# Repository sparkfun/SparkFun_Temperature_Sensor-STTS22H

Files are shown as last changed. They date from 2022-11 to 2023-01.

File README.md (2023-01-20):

SparkFun Temperature Sensor STTS22H
========================================

<table class="table table-hover table-striped table-bordered">
    <tr>
        <th class="text-center"> 
        </th>
        <th class="text-center">
        </th>
    </tr>
    <tr align="center">
        <td></td>
        <td></td>
    </tr>
    <tr align="center">
        <td><a href="https://www.sparkfun.com/products/21262">SparkFun Temperature Sensor - STTS22H (Qwiic)</a></td>
        <td><a href="https://www.sparkfun.com/products/21273">SparkFun Micro Temperature Sensor - STTS22H (Qwiic)</a></td>
    </tr>
</table>

The [SparkFun Temperature Sensor - STTS22H (Qwiic)](https://www.sparkfun.com/products/21262) and the [SparkFun Micro Temperature Sensor - STTS22H (Qwiic)](https://www.sparkfun.com/products/21273) are Qwiic enabled breakout boards based on the ultralow-power, high-accuracy, digital temperature sensor STTS22H from ST Microelectronics. Thanks to its factory calibration the STTS22H offers high-end accuracy performance over the entire operating temperature range, reaching as low as ±0.5 °C without requiring any further calibration at the application level. 

Repository Contents
-------------------

* **/Documentation** - Data sheets, additional product information
* **/Hardware** - Eagle design files (.brd, .sch)
* **/Production** - Production panel files (.brd)

Documentation
--------------
* **[Library](https://github.com/sparkfun/SparkFun_STTS22H_Arduino_Library)** - Arduino library for the SparkFun Temperature Sensor STTS22H.
* **[Hookup Guide](https://learn.sparkfun.com/tutorials/sparkfun-temperature-sensor---stts22h-qwiic-hookup-guide)** - Basic hookup guide for the SparkFun Temperature Sensor STTS22H.

License Information
-------------------

This product is _**open source**_! 

Please review the LICENSE.md file for license information. 

If you have any questions or concerns on licensing, please contact technical support on our [SparkFun forums](https://forum.sparkfun.com/viewforum.php?f=152).

Distributed as-is; no warranty is given.

- Your friends at SparkFun.

_<COLLABORATION CREDIT>_

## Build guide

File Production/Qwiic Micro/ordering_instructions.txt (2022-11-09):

panel size, 170x79mm
PCB thickness, 1.6mm
number of layers, 2
soldermask color, Red
silkscreen color, White
oz copper, 1oz
finish, HASL lead free
stencils, top
pcs per panel, 64
min trace width, 0.1524mm / 0.0060in
min drill size, 0.2032mm / 0.0080in

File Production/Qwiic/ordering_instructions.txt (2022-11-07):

panel size, 169x117mm
PCB thickness, 1.6mm
number of layers, 2
soldermask color, Red
silkscreen color, White
oz copper, 1oz
finish, HASL lead free
stencils, top
pcs per panel, 24
min trace width, 0.2032mm / 0.0080in
min drill size, 0.2032mm / 0.0080in

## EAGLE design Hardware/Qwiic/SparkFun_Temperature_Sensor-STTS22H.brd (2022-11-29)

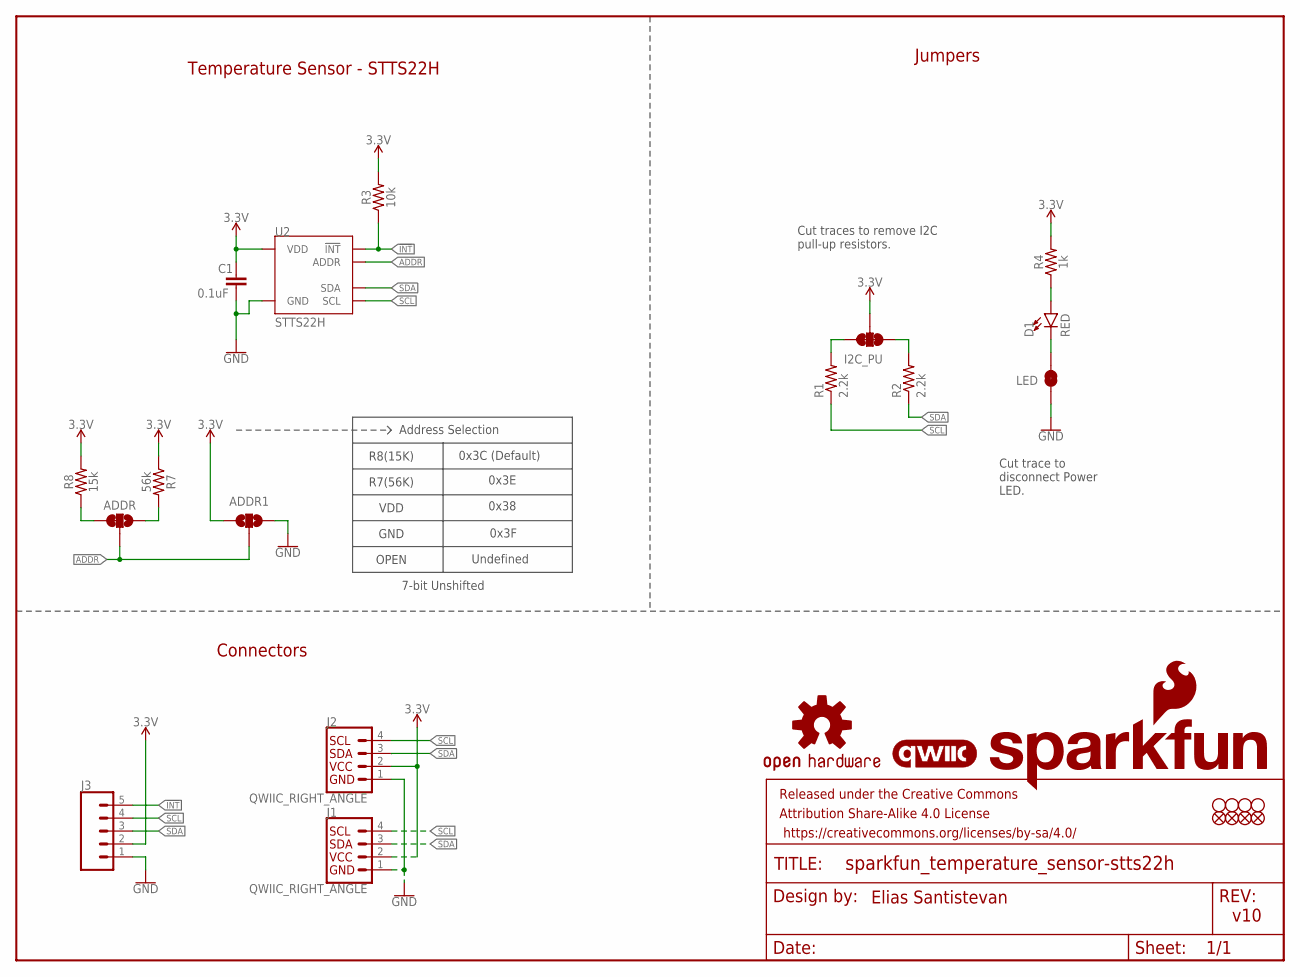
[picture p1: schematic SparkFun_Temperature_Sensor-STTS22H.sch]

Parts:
ADDR: JUMPER-SMT_3_1-NC_TRACE_SILK; SMT-JUMPER_3_1-NC_TRACE_SILK
ADDR1: JUMPER-SMT_3_NO_SILK; SMT-JUMPER_3_NO_SILK
C1: 0.1uF; 0603
D1: RED; LED-0603
FD1, FD2, FD3, FD4: FIDUCIAL1X2; FIDUCIAL-1X2
FRAME1: FRAME-LETTER; CREATIVE_COMMONS
I2C_PU: S_MODE; SMT-JUMPER_3_2-NC_TRACE_SILK
J1, J2: QWIIC_RIGHT_ANGLE; JST04_1MM_RA
J3: CONN_05NO_SILK; 1X05_NO_SILK
LED: JUMPER-SMT_2_NC_TRACE_SILK; SMT-JUMPER_2_NC_TRACE_SILK
LOGO2: OSHW-LOGOMINI; OSHW-LOGO-MINI
LOGO3: SFE_LOGO_NAME_FLAME.1_INCH; SFE_LOGO_NAME_FLAME_.1
LOGO4: QWIIC_LOGO_4MM; QWIIC_4MM
R1, R2: 2.2k; 0603
R3: 10k; 0603
R4: 1k; 0603
R7: 56k; 0603
R8: 15k; 0603
STANDOFF1, STANDOFF2, STANDOFF3, STANDOFF5: STAND-OFFTIGHT; STAND-OFF-TIGHT
U2: STTS22H; UDFN-6L

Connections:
3.3V: ADDR1.3, C1.1, I2C_PU.2, J1.2, J2.2, J3.2, R3.2, R4.2, R7.1, R8.2, U2.P3 (VDD)
!INT!: J3.5, R3.1, U2.P2 (!INT!)
ADDR: ADDR.2, ADDR1.2, U2.P4 (ADDR)
GND: ADDR1.1, C1.2, J1.1, J2.1, J3.1, LED.1, U2.P5 (GND), U2.P7 (GND)
unnamed: D1.A, R4.1
unnamed: D1.C, LED.2
unnamed: ADDR.3, R8.1
unnamed: I2C_PU.1, R1.2
unnamed: I2C_PU.3, R2.2
unnamed: ADDR.1, R7.2
SCL: J1.4, J2.4, J3.4, R1.1, U2.P1 (SCL)
SDA: J1.3, J2.3, J3.3, R2.1, U2.P6 (SDA)

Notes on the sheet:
Cut traces to remove I2C pull-up resistors.
v10
Jumpers
Cut trace to disconnect Power LED.
Connectors
Elias Santistevan
VDD
GND
OPEN
Undefined
7-bit Unshifted
R7(56K)
R8(15K)
0x38
0x3C (Default)
0x3E
0x3F
Temperature Sensor - STTS22H
Address Selection

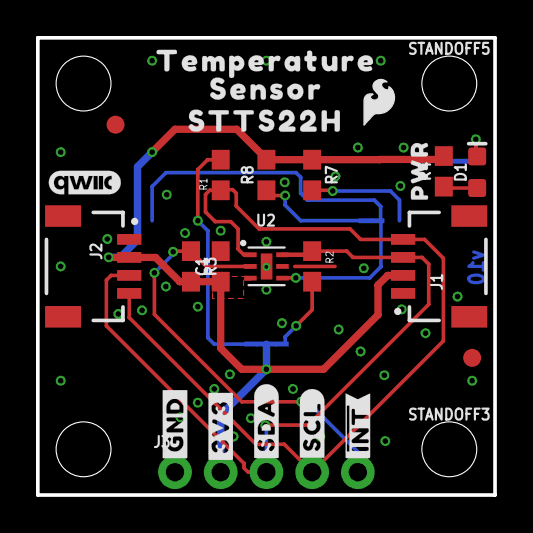
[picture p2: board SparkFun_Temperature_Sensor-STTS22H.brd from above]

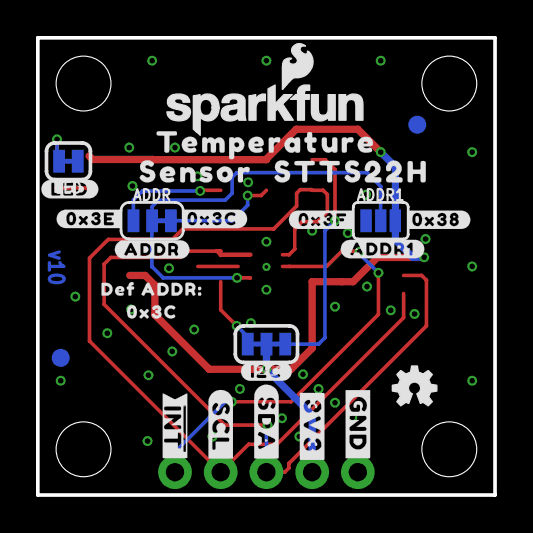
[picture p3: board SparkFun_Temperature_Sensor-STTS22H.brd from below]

Board: 2 copper layers, 25.4 x 25.4 mm, 56 parts (26 on the bottom side), 12 nets.

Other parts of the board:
U$1, U$9: #GND#3
U$2, U$10: #3V3#4
U$3: #SDA#5
U$4: #SCL#4
U$5: #SDA#7
U$6: #ADDR#6
U$7: #SCL#6
U$8: #ADDR1#9
U$11: ##INT##9
U$12: #0X3C#25
U$13: #0X3E#25
U$14: #0X3F#25
U$15: #0X38#25
U$16: #LED#11
U$17, U$23: TEMPERATURE23
U$18: ##INT##6
U$19, U$24: SENSOR24
U$20: SFE_LOGO_FLAME_.1
U$21: PWR9
U$22, U$26: STTS22H21
U$25: #I2C#11
U$27: DEF_ADDR#29
U$28: 0X3C30

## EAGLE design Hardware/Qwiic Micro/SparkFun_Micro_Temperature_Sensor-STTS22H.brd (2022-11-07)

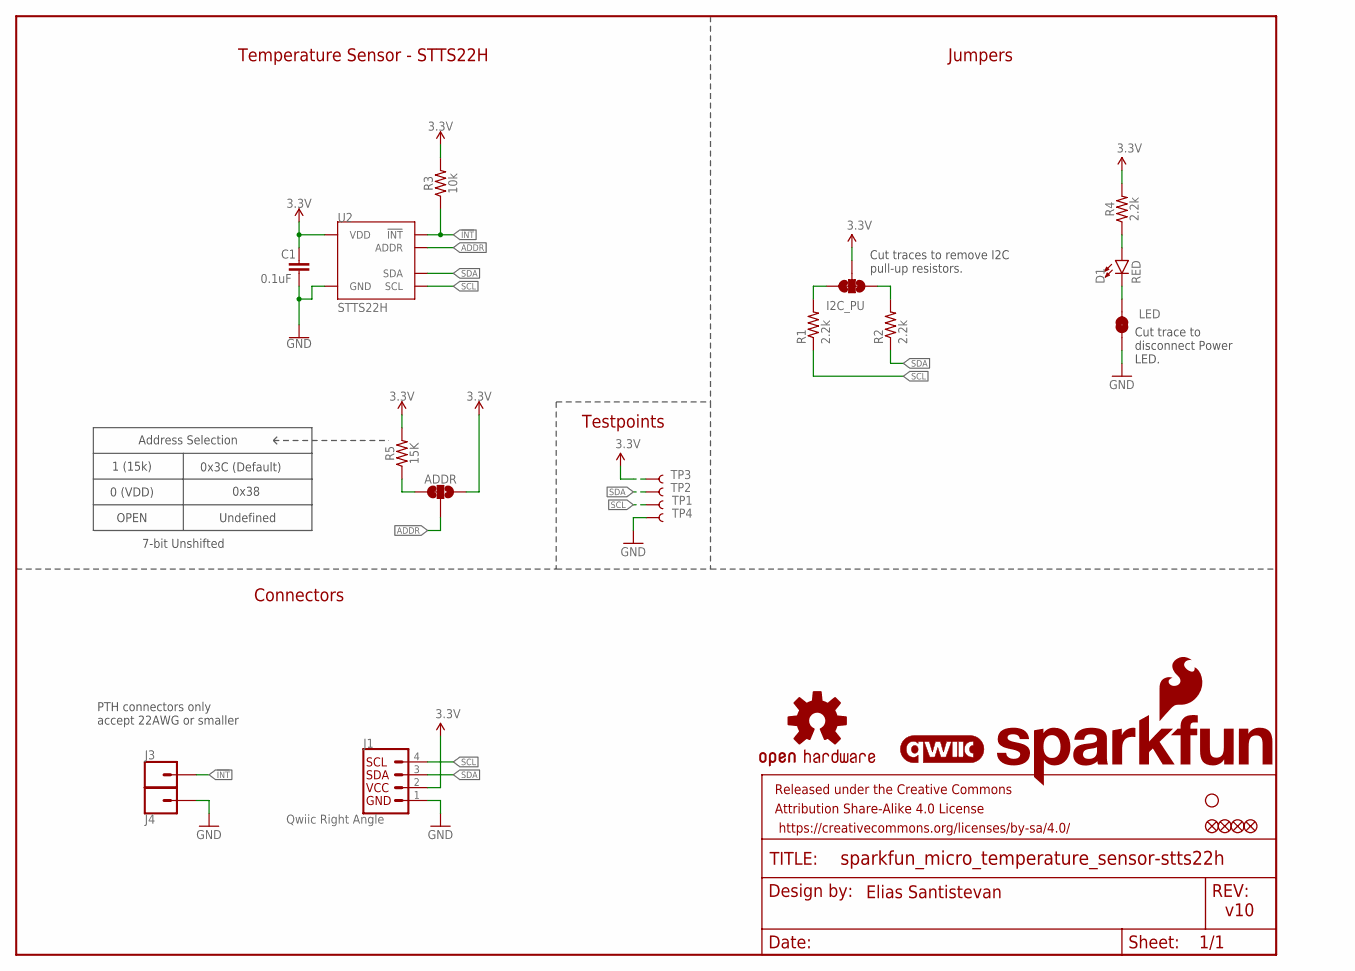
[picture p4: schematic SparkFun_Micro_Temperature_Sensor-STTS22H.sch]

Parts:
ADDR: JUMPER-SMT_3_1-NC_TRACE_SILK; SMT-JUMPER_3_1-NC_TRACE_SILK
C1: 0.1uF; 0402-TIGHT
D1: RED; LED-0402
FD1, FD2: FIDUCIALUFIDUCIAL; FIDUCIAL-MICRO
FID1, FID2: FIDUCIALUFIDUCIAL; FIDUCIAL-MICRO
FRAME1: FRAME-LETTER; CREATIVE_COMMONS
I2C_PU: S_MODE; SMT-JUMPER_3_2-NC_TRACE_SILK
J1: Qwiic Right Angle; JST04_1MM_RA
J3, J4: CONN_01_1MM; 1X01_1MM_NO_SILK
LED: JUMPER-SMT_2_NC_TRACE_SILK; SMT-JUMPER_2_NC_TRACE_SILK
LOGO1: QWIIC_LOGO_3MM; QWIIC_3MM
LOGO2: OSHW-LOGOMINI; OSHW-LOGO-MINI
LOGO3: SFE_LOGO_NAME_FLAMEBLANK; BLANK
R1, R2, R4: 2.2k; 0402-TIGHT
R3: 10k; 0402-TIGHT
R5: 15K; 0402-TIGHT
STANDOFF1: STAND-OFFTIGHT; STAND-OFF-TIGHT
TP1, TP2, TP3, TP4: TEST-POINT3; PAD.03X.03
U2: STTS22H; UDFN-6L

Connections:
3.3V: ADDR.1, C1.1, I2C_PU.2, J1.2, R3.2, R4.2, R5.2, TP3.1, U2.P3 (VDD)
!INT!: J3.1, R3.1, U2.P2 (!INT!)
ADDR: ADDR.2, U2.P4 (ADDR)
GND: C1.2, J1.1, J4.1, LED.1, TP4.1, U2.P5 (GND), U2.P7 (GND)
unnamed: ADDR.3, R5.1
unnamed: D1.A, R4.1
unnamed: D1.C, LED.2
unnamed: I2C_PU.1, R1.2
unnamed: I2C_PU.3, R2.2
SCL: J1.4, R1.1, TP1.1, U2.P1 (SCL)
SDA: J1.3, R2.1, TP2.1, U2.P6 (SDA)

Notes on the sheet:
Cut traces to remove I2C pull-up resistors.
v10
Jumpers
Cut trace to disconnect Power LED.
Connectors
Elias Santistevan
Testpoints
PTH connectors only accept 22AWG or smaller
1 (15k)
0 (VDD)
OPEN
Undefined
7-bit Unshifted
0x3C (Default)
0x38
Temperature Sensor - STTS22H
Address Selection

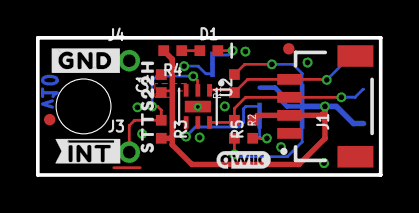
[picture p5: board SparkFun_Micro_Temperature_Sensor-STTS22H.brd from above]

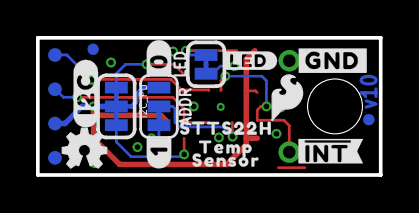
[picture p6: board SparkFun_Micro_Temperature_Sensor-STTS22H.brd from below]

Board: 2 copper layers, 19.1 x 7.6 mm, 40 parts (20 on the bottom side), 11 nets.

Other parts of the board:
U$1: #0#4
U$2: #1#4
U$3: #LED#2121
U$4, U$10: #GND#4
U$5, U$6: ##INT##9
U$7, U$8: STTS22H11
U$9: TEMP24
U$11: SENSOR25
U$12: #I2C#4
U$29: SFE_LOGO_FLAME_.1

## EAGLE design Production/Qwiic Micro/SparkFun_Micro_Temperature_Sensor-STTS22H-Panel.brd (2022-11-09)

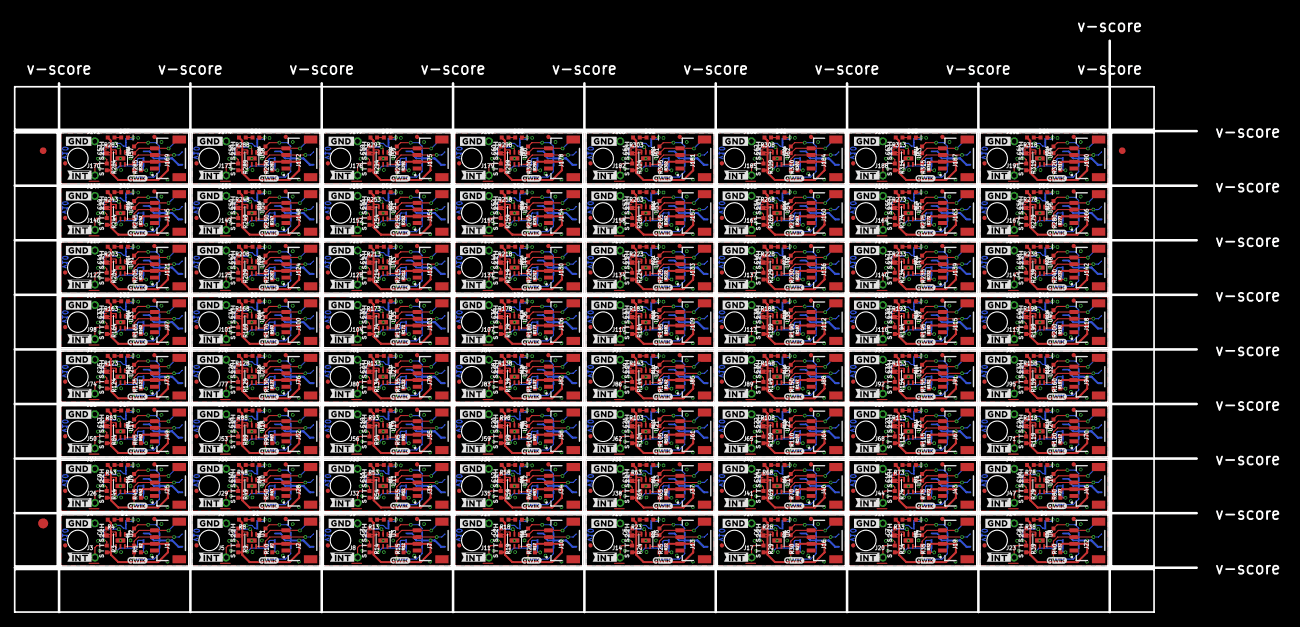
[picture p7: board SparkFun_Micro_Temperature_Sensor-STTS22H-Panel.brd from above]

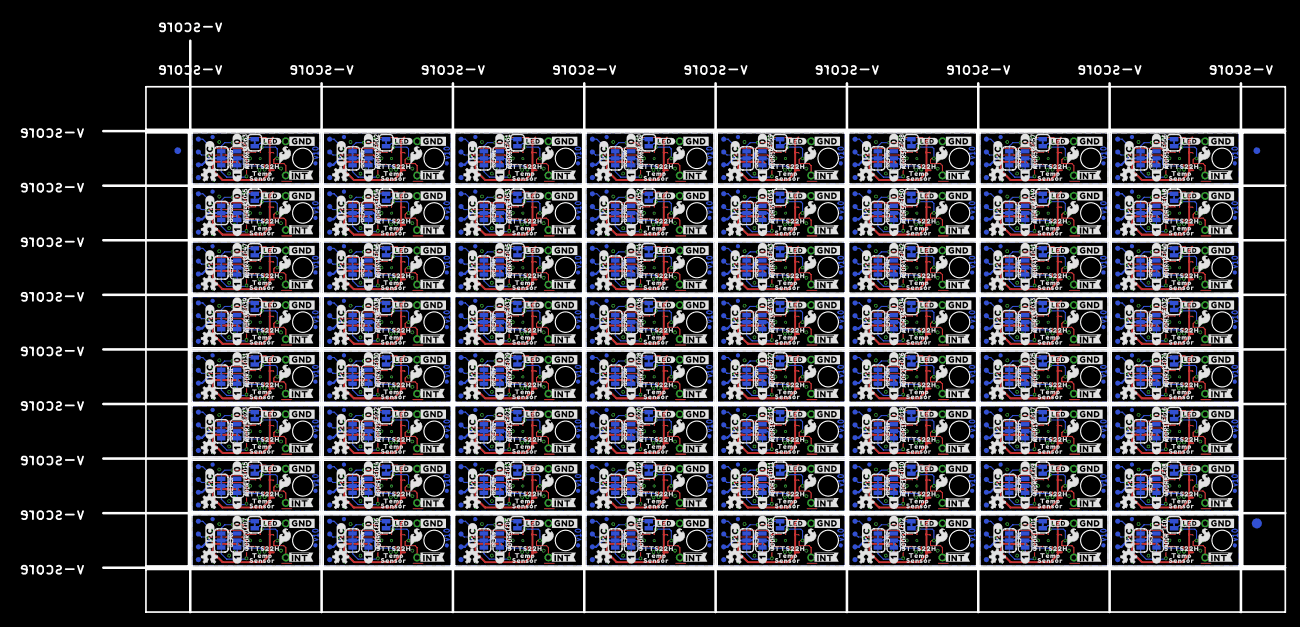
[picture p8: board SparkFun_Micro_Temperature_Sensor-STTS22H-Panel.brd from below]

Board: 2 copper layers, 176.0 x 85.1 mm, 2502 parts (1283 on the bottom side), 704 nets.

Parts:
ADDR, ADDR1, ADDR2, ADDR3, ADDR4, ADDR5, ADDR6, ADDR7, ADDR8, ADDR9, ADDR10, ADDR11, ADDR12, ADDR13, ADDR14, ADDR15, ADDR16, ADDR17, ADDR18, ADDR19, ADDR20, ADDR21, ADDR22, ADDR23, ADDR24, ADDR25, ADDR26, ADDR27, ADDR28, ADDR29, ADDR30, ADDR31, ADDR32, ADDR33, ADDR34, ADDR35, ADDR36, ADDR37, ADDR38, ADDR39, ADDR40, ADDR41, ADDR42, ADDR43, ADDR44, ADDR45, ADDR46, ADDR47, ADDR48, ADDR49, ADDR50, ADDR51, ADDR52, ADDR53, ADDR54, ADDR55, ADDR56, ADDR57, ADDR58, ADDR59, ADDR60, ADDR61, ADDR62, ADDR63: JUMPER-SMT_3_1-NC_TRACE_SILK; SMT-JUMPER_3_1-NC_TRACE_SILK
C1, C2, C3, C4, C5, C6, C7, C8, C9, C10, C11, C12, C13, C14, C15, C16, C17, C18, C19, C20, C21, C22, C23, C24, C25, C26, C27, C28, C29, C30, C31, C32, C33, C34, C35, C36, C37, C38, C39, C40, C41, C42, C43, C44, C45, C46, C47, C48, C49, C50, C51, C52, C53, C54, C55, C56, C57, C58, C59, C60, C61, C62, C63, C64: 0.1uF; 0402-TIGHT
D1, D2, D3, D4, D5, D6, D7, D8, D9, D10, D11, D12, D13, D14, D15, D16, D17, D18, D19, D20, D21, D22, D23, D24, D25, D26, D27, D28, D29, D30, D31, D32, D33, D34, D35, D36, D37, D38, D39, D40, D41, D42, D43, D44, D45, D46, D47, D48, D49, D50, D51, D52, D53, D54, D55, D56, D57, D58, D59, D60, D61, D62, D63, D64: RED; LED-0402
E$1, E$2, E$3, E$4: FIDUCIAL-1X2
E$5, E$6: FIDUCIAL-1.5X3
FD1, FD2, FD3, FD4, FD5, FD6, FD7, FD8, FD9, FD10, FD11, FD12, FD13, FD14, FD15, FD16, FD17, FD18, FD19, FD20, FD21, FD22, FD23, FD24, FD25, FD26, FD27, FD28, FD29, FD30, FD31, FD32, FD33, FD34, FD35, FD36, FD37, FD38, FD39, FD40, FD41, FD42, FD43, FD44, FD45, FD46, FD47, FD48, FD49, FD50, FD51, FD52, FD53, FD54, FD55, FD56, FD57, FD58, FD59, FD60, FD61, FD62, FD63, FD64, FD65, FD66, FD67, FD68, FD69, FD70, FD71, FD72, FD73, FD74, FD75, FD76, FD77, FD78, FD79, FD80, FD81, FD82, FD83, FD84, FD85, FD86, FD87, FD88, FD89, FD90, FD91, FD92, FD93, FD94, FD95, FD96, FD97, FD98, FD99, FD100, FD101, FD102, FD103, FD104, FD105, FD106, FD107, FD108, FD109, FD110, FD111, FD112, FD113, FD114, FD115, FD116, FD117, FD118, FD119, FD120, FD121, FD122, FD123, FD124, FD125, FD126, FD127, FD128: FIDUCIALUFIDUCIAL; FIDUCIAL-MICRO
FID1, FID2, FID3, FID4, FID5, FID6, FID7, FID8, FID9, FID10, FID11, FID12, FID13, FID14, FID15, FID16, FID17, FID18, FID19, FID20, FID21, FID22, FID23, FID24, FID25, FID26, FID27, FID28, FID29, FID30, FID31, FID32, FID33, FID34, FID35, FID36, FID37, FID38, FID39, FID40, FID41, FID42, FID43, FID44, FID45, FID46, FID47, FID48, FID49, FID50, FID51, FID52, FID53, FID54, FID55, FID56, FID57, FID58, FID59, FID60, FID61, FID62, FID63, FID64, FID65, FID66, FID67, FID68, FID69, FID70, FID71, FID72, FID73, FID74, FID75, FID76, FID77, FID78, FID79, FID80, FID81, FID82, FID83, FID84, FID85, FID86, FID87, FID88, FID89, FID90, FID91, FID92, FID93, FID94, FID95, FID96, FID97, FID98, FID99, FID100, FID101, FID102, FID103, FID104, FID105, FID106, FID107, FID108, FID109, FID110, FID111, FID112, FID113, FID114, FID115, FID116, FID117, FID118, FID119, FID120, FID121, FID122, FID123, FID124, FID125, FID126, FID127, FID128: FIDUCIALUFIDUCIAL; FIDUCIAL-MICRO
I2C_PU, I2C_PU1, I2C_PU2, I2C_PU3, I2C_PU4, I2C_PU5, I2C_PU6, I2C_PU7, I2C_PU8, I2C_PU9, I2C_PU10, I2C_PU11, I2C_PU12, I2C_PU13, I2C_PU14, I2C_PU15, I2C_PU16, I2C_PU17, I2C_PU18, I2C_PU19, I2C_PU20, I2C_PU21, I2C_PU22, I2C_PU23, I2C_PU24, I2C_PU25, I2C_PU26, I2C_PU27, I2C_PU28, I2C_PU29, I2C_PU30, I2C_PU31, I2C_PU32, I2C_PU33, I2C_PU34, I2C_PU35, I2C_PU36, I2C_PU37, I2C_PU38, I2C_PU39, I2C_PU40, I2C_PU41, I2C_PU42, I2C_PU43, I2C_PU44, I2C_PU45, I2C_PU46, I2C_PU47, I2C_PU48, I2C_PU49, I2C_PU50, I2C_PU51, I2C_PU52, I2C_PU53, I2C_PU54, I2C_PU55, I2C_PU56, I2C_PU57, I2C_PU58, I2C_PU59, I2C_PU60, I2C_PU61, I2C_PU62, I2C_PU63: S_MODE; SMT-JUMPER_3_2-NC_TRACE_SILK
J1, J2, J7, J10, J13, J16, J19, J22, J25, J28, J31, J34, J37, J40, J43, J46, J49, J52, J55, J58, J61, J64, J67, J70, J73, J76, J79, J82, J85, J88, J91, J94, J97, J100, J103, J106, J109, J112, J115, J118, J121, J124, J127, J130, J133, J136, J139, J142, J145, J148, J151, J154, J157, J160, J163, J166, J169, J172, J175, J178, J181, J184, J187, J190: Qwiic Right Angle; JST04_1MM_RA
J3, J4, J5, J6, J8, J9, J11, J12, J14, J15, J17, J18, J20, J21, J23, J24, J26, J27, J29, J30, J32, J33, J35, J36, J38, J39, J41, J42, J44, J45, J47, J48, J50, J51, J53, J54, J56, J57, J59, J60, J62, J63, J65, J66, J68, J69, J71, J72, J74, J75, J77, J78, J80, J81, J83, J84, J86, J87, J89, J90, J92, J93, J95, J96, J98, J99, J101, J102, J104, J105, J107, J108, J110, J111, J113, J114, J116, J117, J119, J120, J122, J123, J125, J126, J128, J129, J131, J132, J134, J135, J137, J138, J140, J141, J143, J144, J146, J147, J149, J150, J152, J153, J155, J156, J158, J159, J161, J162, J164, J165, J167, J168, J170, J171, J173, J174, J176, J177, J179, J180, J182, J183, J185, J186, J188, J189, J191, J192: 1X01_1MM_NO_SILK
LED, LED1, LED2, LED3, LED4, LED5, LED6, LED7, LED8, LED9, LED10, LED11, LED12, LED13, LED14, LED15, LED16, LED17, LED18, LED19, LED20, LED21, LED22, LED23, LED24, LED25, LED26, LED27, LED28, LED29, LED30, LED31, LED32, LED33, LED34, LED35, LED36, LED37, LED38, LED39, LED40, LED41, LED42, LED43, LED44, LED45, LED46, LED47, LED48, LED49, LED50, LED51, LED52, LED53, LED54, LED55, LED56, LED57, LED58, LED59, LED60, LED61, LED62, LED63: JUMPER-SMT_2_NC_TRACE_SILK; SMT-JUMPER_2_NC_TRACE_SILK
LOGO1, LOGO5, LOGO8, LOGO11, LOGO14, LOGO17, LOGO20, LOGO23, LOGO26, LOGO29, LOGO32, LOGO35, LOGO38, LOGO41, LOGO44, LOGO47, LOGO50, LOGO53, LOGO56, LOGO59, LOGO62, LOGO65, LOGO68, LOGO71, LOGO74, LOGO77, LOGO80, LOGO83, LOGO86, LOGO89, LOGO92, LOGO95, LOGO98, LOGO101, LOGO104, LOGO107, LOGO110, LOGO113, LOGO116, LOGO119, LOGO122, LOGO125, LOGO128, LOGO131, LOGO134, LOGO137, LOGO140, LOGO143, LOGO146, LOGO149, LOGO152, LOGO155, LOGO158, LOGO161, LOGO164, LOGO167, LOGO170, LOGO173, LOGO176, LOGO179, LOGO182, LOGO185, LOGO188, LOGO191: QWIIC_LOGO_3MM; QWIIC_3MM
LOGO2, LOGO4, LOGO7, LOGO10, LOGO13, LOGO16, LOGO19, LOGO22, LOGO25, LOGO28, LOGO31, LOGO34, LOGO37, LOGO40, LOGO43, LOGO46, LOGO49, LOGO52, LOGO55, LOGO58, LOGO61, LOGO64, LOGO67, LOGO70, LOGO73, LOGO76, LOGO79, LOGO82, LOGO85, LOGO88, LOGO91, LOGO94, LOGO97, LOGO100, LOGO103, LOGO106, LOGO109, LOGO112, LOGO115, LOGO118, LOGO121, LOGO124, LOGO127, LOGO130, LOGO133, LOGO136, LOGO139, LOGO142, LOGO145, LOGO148, LOGO151, LOGO154, LOGO157, LOGO160, LOGO163, LOGO166, LOGO169, LOGO172, LOGO175, LOGO178, LOGO181, LOGO184, LOGO187, LOGO190: OSHW-LOGOMINI; OSHW-LOGO-MINI
LOGO3, LOGO6, LOGO9, LOGO12, LOGO15, LOGO18, LOGO21, LOGO24, LOGO27, LOGO30, LOGO33, LOGO36, LOGO39, LOGO42, LOGO45, LOGO48, LOGO51, LOGO54, LOGO57, LOGO60, LOGO63, LOGO66, LOGO69, LOGO72, LOGO75, LOGO78, LOGO81, LOGO84, LOGO87, LOGO90, LOGO93, LOGO96, LOGO99, LOGO102, LOGO105, LOGO108, LOGO111, LOGO114, LOGO117, LOGO120, LOGO123, LOGO126, LOGO129, LOGO132, LOGO135, LOGO138, LOGO141, LOGO144, LOGO147, LOGO150, LOGO153, LOGO156, LOGO159, LOGO162, LOGO165, LOGO168, LOGO171, LOGO174, LOGO177, LOGO180, LOGO183, LOGO186, LOGO189, LOGO192: SFE_LOGO_NAME_FLAMEBLANK; BLANK
R1, R2, R4, R6, R7, R8, R11, R12, R13, R16, R17, R18, R21, R22, R23, R26, R27, R28, R31, R32, R33, R36, R37, R38, R41, R42, R43, R46, R47, R48, R51, R52, R53, R56, R57, R58, R61, R62, R63, R66, R67, R68, R71, R72, R73, R76, R77, R78, R81, R82, R83, R86, R87, R88, R91, R92, R93, R96, R97, R98, R101, R102, R103, R106, R107, R108, R111, R112, R113, R116, R117, R118, R121, R122, R123, R126, R127, R128, R131, R132, R133, R136, R137, R138, R141, R142, R143, R146, R147, R148, R151, R152, R153, R156, R157, R158, R161, R162, R163, R166, R167, R168, R171, R172, R173, R176, R177, R178, R181, R182, R183, R186, R187, R188, R191, R192, R193, R196, R197, R198, R201, R202, R203, R206, R207, R208, R211, R212, R213, R216, R217, R218, R221, R222, R223, R226, R227, R228, R231, R232, R233, R236, R237, R238, R241, R242, R243, R246, R247, R248, R251, R252, R253, R256, R257, R258, R261, R262, R263, R266, R267, R268, R271, R272, R273, R276, R277, R278, R281, R282, R283, R286, R287, R288, R291, R292, R293, R296, R297, R298, R301, R302, R303, R306, R307, R308, R311, R312, R313, R316, R317, R318: 2.2k; 0402-TIGHT
R3, R9, R14, R19, R24, R29, R34, R39, R44, R49, R54, R59, R64, R69, R74, R79, R84, R89, R94, R99, R104, R109, R114, R119, R124, R129, R134, R139, R144, R149, R154, R159, R164, R169, R174, R179, R184, R189, R194, R199, R204, R209, R214, R219, R224, R229, R234, R239, R244, R249, R254, R259, R264, R269, R274, R279, R284, R289, R294, R299, R304, R309, R314, R319: 10k; 0402-TIGHT
R5, R10, R15, R20, R25, R30, R35, R40, R45, R50, R55, R60, R65, R70, R75, R80, R85, R90, R95, R100, R105, R110, R115, R120, R125, R130, R135, R140, R145, R150, R155, R160, R165, R170, R175, R180, R185, R190, R195, R200, R205, R210, R215, R220, R225, R230, R235, R240, R245, R250, R255, R260, R265, R270, R275, R280, R285, R290, R295, R300, R305, R310, R315, R320: 15K; 0402-TIGHT
STANDOFF1, STANDOFF2, STANDOFF3, STANDOFF4, STANDOFF5, STANDOFF6, STANDOFF7, STANDOFF8, STANDOFF9, STANDOFF10, STANDOFF11, STANDOFF12, STANDOFF13, STANDOFF14, STANDOFF15, STANDOFF16, STANDOFF17, STANDOFF18, STANDOFF19, STANDOFF20, STANDOFF21, STANDOFF22, STANDOFF23, STANDOFF24, STANDOFF25, STANDOFF26, STANDOFF27, STANDOFF28, STANDOFF29, STANDOFF30, STANDOFF31, STANDOFF32, STANDOFF33, STANDOFF34, STANDOFF35, STANDOFF36, STANDOFF37, STANDOFF38, STANDOFF39, STANDOFF40, STANDOFF41, STANDOFF42, STANDOFF43, STANDOFF44, STANDOFF45, STANDOFF46, STANDOFF47, STANDOFF48, STANDOFF49, STANDOFF50, STANDOFF51, STANDOFF52, STANDOFF53, STANDOFF54, STANDOFF55, STANDOFF56, STANDOFF57, STANDOFF58, STANDOFF59, STANDOFF60, STANDOFF61, STANDOFF62, STANDOFF63, STANDOFF64: STAND-OFFTIGHT; STAND-OFF-TIGHT
TP1, TP2, TP3, TP4, TP5, TP6, TP7, TP8, TP9, TP10, TP11, TP12, TP13, TP14, TP15, TP16, TP17, TP18, TP19, TP20, TP21, TP22, TP23, TP24, TP25, TP26, TP27, TP28, TP29, TP30, TP31, TP32, TP33, TP34, TP35, TP36, TP37, TP38, TP39, TP40, TP41, TP42, TP43, TP44, TP45, TP46, TP47, TP48, TP49, TP50, TP51, TP52, TP53, TP54, TP55, TP56, TP57, TP58, TP59, TP60, TP61, TP62, TP63, TP64, TP65, TP66, TP67, TP68, TP69, TP70, TP71, TP72, TP73, TP74, TP75, TP76, TP77, TP78, TP79, TP80, TP81, TP82, TP83, TP84, TP85, TP86, TP87, TP88, TP89, TP90, TP91, TP92, TP93, TP94, TP95, TP96, TP97, TP98, TP99, TP100, TP101, TP102, TP103, TP104, TP105, TP106, TP107, TP108, TP109, TP110, TP111, TP112, TP113, TP114, TP115, TP116, TP117, TP118, TP119, TP120, TP121, TP122, TP123, TP124, TP125, TP126, TP127, TP128, TP129, TP130, TP131, TP132, TP133, TP134, TP135, TP136, TP137, TP138, TP139, TP140, TP141, TP142, TP143, TP144, TP145, TP146, TP147, TP148, TP149, TP150, TP151, TP152, TP153, TP154, TP155, TP156, TP157, TP158, TP159, TP160, TP161, TP162, TP163, TP164, TP165, TP166, TP167, TP168, TP169, TP170, TP171, TP172, TP173, TP174, TP175, TP176, TP177, TP178, TP179, TP180, TP181, TP182, TP183, TP184, TP185, TP186, TP187, TP188, TP189, TP190, TP191, TP192, TP193, TP194, TP195, TP196, TP197, TP198, TP199, TP200, TP201, TP202, TP203, TP204, TP205, TP206, TP207, TP208, TP209, TP210, TP211, TP212, TP213, TP214, TP215, TP216, TP217, TP218, TP219, TP220, TP221, TP222, TP223, TP224, TP225, TP226, TP227, TP228, TP229, TP230, TP231, TP232, TP233, TP234, TP235, TP236, TP237, TP238, TP239, TP240, TP241, TP242, TP243, TP244, TP245, TP246, TP247, TP248, TP249, TP250, TP251, TP252, TP253, TP254, TP255, TP256: TEST-POINT3; PAD.03X.03
U1, U2, U3, U4, U5, U6, U7, U8, U9, U10, U11, U12, U13, U14, U15, U16, U17, U18, U19, U20, U21, U22, U23, U24, U25, U26, U27, U28, U29, U30, U31, U32, U33, U34, U35, U36, U37, U38, U39, U40, U41, U42, U43, U44, U45, U46, U47, U48, U49, U50, U51, U52, U53, U54, U55, U56, U57, U58, U59, U60, U61, U62, U63, U64: STTS22H; UDFN-6L
U$1, U$15, U$28, U$42, U$55, U$68, U$81, U$94, U$107, U$120, U$133, U$146, U$159, U$172, U$185, U$198, U$211, U$224, U$237, U$250, U$263, U$276, U$289, U$302, U$315, U$328, U$341, U$354, U$367, U$380, U$393, U$406, U$419, U$432, U$445, U$458, U$471, U$484, U$497, U$510, U$523, U$536, U$549, U$562, U$575, U$588, U$601, U$614, U$627, U$640, U$653, U$666, U$679, U$692, U$705, U$718, U$731, U$744, U$757, U$770, U$783, U$796, U$809, U$822: #0#4
U$2, U$16, U$30, U$43, U$56, U$69, U$82, U$95, U$108, U$121, U$134, U$147, U$160, U$173, U$186, U$199, U$212, U$225, U$238, U$251, U$264, U$277, U$290, U$303, U$316, U$329, U$342, U$355, U$368, U$381, U$394, U$407, U$420, U$433, U$446, U$459, U$472, U$485, U$498, U$511, U$524, U$537, U$550, U$563, U$576, U$589, U$602, U$615, U$628, U$641, U$654, U$667, U$680, U$693, U$706, U$719, U$732, U$745, U$758, U$771, U$784, U$797, U$810, U$823: #1#4
U$3, U$14, U$27, U$41, U$54, U$67, U$80, U$93, U$106, U$119, U$132, U$145, U$158, U$171, U$184, U$197, U$210, U$223, U$236, U$249, U$262, U$275, U$288, U$301, U$314, U$327, U$340, U$353, U$366, U$379, U$392, U$405, U$418, U$431, U$444, U$457, U$470, U$483, U$496, U$509, U$522, U$535, U$548, U$561, U$574, U$587, U$600, U$613, U$626, U$639, U$652, U$665, U$678, U$691, U$704, U$717, U$730, U$743, U$756, U$769, U$782, U$795, U$808, U$821: #LED#2121
U$4, U$10, U$18, U$19, U$32, U$33, U$45, U$46, U$58, U$59, U$71, U$72, U$84, U$85, U$97, U$98, U$110, U$111, U$123, U$124, U$136, U$137, U$149, U$150, U$162, U$163, U$175, U$176, U$188, U$189, U$201, U$202, U$214, U$215, U$227, U$228, U$240, U$241, U$253, U$254, U$266, U$267, U$279, U$280, U$292, U$293, U$305, U$306, U$318, U$319, U$331, U$332, U$344, U$345, U$357, U$358, U$370, U$371, U$383, U$384, U$396, U$397, U$409, U$410, U$422, U$423, U$435, U$436, U$448, U$449, U$461, U$462, U$474, U$475, U$487, U$488, U$500, U$501, U$513, U$514, U$526, U$527, U$539, U$540, U$552, U$553, U$565, U$566, U$578, U$579, U$591, U$592, U$604, U$605, U$617, U$618, U$630, U$631, U$643, U$644, U$656, U$657, U$669, U$670, U$682, U$683, U$695, U$696, U$708, U$709, U$721, U$722, U$734, U$735, U$747, U$748, U$760, U$761, U$773, U$774, U$786, U$787, U$799, U$800, U$812, U$813, U$825, U$826: #GND#4
U$5, U$6, U$20, U$21, U$34, U$35, U$47, U$48, U$60, U$61, U$73, U$74, U$86, U$87, U$99, U$100, U$112, U$113, U$125, U$126, U$138, U$139, U$151, U$152, U$164, U$165, U$177, U$178, U$190, U$191, U$203, U$204, U$216, U$217, U$229, U$230, U$242, U$243, U$255, U$256, U$268, U$269, U$281, U$282, U$294, U$295, U$307, U$308, U$320, U$321, U$333, U$334, U$346, U$347, U$359, U$360, U$372, U$373, U$385, U$386, U$398, U$399, U$411, U$412, U$424, U$425, U$437, U$438, U$450, U$451, U$463, U$464, U$476, U$477, U$489, U$490, U$502, U$503, U$515, U$516, U$528, U$529, U$541, U$542, U$554, U$555, U$567, U$568, U$580, U$581, U$593, U$594, U$606, U$607, U$619, U$620, U$632, U$633, U$645, U$646, U$658, U$659, U$671, U$672, U$684, U$685, U$697, U$698, U$710, U$711, U$723, U$724, U$736, U$737, U$749, U$750, U$762, U$763, U$775, U$776, U$788, U$789, U$801, U$802, U$814, U$815, U$827, U$828: ##INT##9
U$7, U$8, U$22, U$23, U$36, U$37, U$49, U$50, U$62, U$63, U$75, U$76, U$88, U$89, U$101, U$102, U$114, U$115, U$127, U$128, U$140, U$141, U$153, U$154, U$166, U$167, U$179, U$180, U$192, U$193, U$205, U$206, U$218, U$219, U$231, U$232, U$244, U$245, U$257, U$258, U$270, U$271, U$283, U$284, U$296, U$297, U$309, U$310, U$322, U$323, U$335, U$336, U$348, U$349, U$361, U$362, U$374, U$375, U$387, U$388, U$400, U$401, U$413, U$414, U$426, U$427, U$439, U$440, U$452, U$453, U$465, U$466, U$478, U$479, U$491, U$492, U$504, U$505, U$517, U$518, U$530, U$531, U$543, U$544, U$556, U$557, U$569, U$570, U$582, U$583, U$595, U$596, U$608, U$609, U$621, U$622, U$634, U$635, U$647, U$648, U$660, U$661, U$673, U$674, U$686, U$687, U$699, U$700, U$712, U$713, U$725, U$726, U$738, U$739, U$751, U$752, U$764, U$765, U$777, U$778, U$790, U$791, U$803, U$804, U$816, U$817, U$829, U$830: STTS22H11
U$9, U$24, U$38, U$51, U$64, U$77, U$90, U$103, U$116, U$129, U$142, U$155, U$168, U$181, U$194, U$207, U$220, U$233, U$246, U$259, U$272, U$285, U$298, U$311, U$324, U$337, U$350, U$363, U$376, U$389, U$402, U$415, U$428, U$441, U$454, U$467, U$480, U$493, U$506, U$519, U$532, U$545, U$558, U$571, U$584, U$597, U$610, U$623, U$636, U$649, U$662, U$675, U$688, U$701, U$714, U$727, U$740, U$753, U$766, U$779, U$792, U$805, U$818, U$831: TEMP24
U$11, U$25, U$39, U$52, U$65, U$78, U$91, U$104, U$117, U$130, U$143, U$156, U$169, U$182, U$195, U$208, U$221, U$234, U$247, U$260, U$273, U$286, U$299, U$312, U$325, U$338, U$351, U$364, U$377, U$390, U$403, U$416, U$429, U$442, U$455, U$468, U$481, U$494, U$507, U$520, U$533, U$546, U$559, U$572, U$585, U$598, U$611, U$624, U$637, U$650, U$663, U$676, U$689, U$702, U$715, U$728, U$741, U$754, U$767, U$780, U$793, U$806, U$819, U$832: SENSOR25
U$12, U$17, U$31, U$44, U$57, U$70, U$83, U$96, U$109, U$122, U$135, U$148, U$161, U$174, U$187, U$200, U$213, U$226, U$239, U$252, U$265, U$278, U$291, U$304, U$317, U$330, U$343, U$356, U$369, U$382, U$395, U$408, U$421, U$434, U$447, U$460, U$473, U$486, U$499, U$512, U$525, U$538, U$551, U$564, U$577, U$590, U$603, U$616, U$629, U$642, U$655, U$668, U$681, U$694, U$707, U$720, U$733, U$746, U$759, U$772, U$785, U$798, U$811, U$824: #I2C#4
U$13, U$26, U$29, U$40, U$53, U$66, U$79, U$92, U$105, U$118, U$131, U$144, U$157, U$170, U$183, U$196, U$209, U$222, U$235, U$248, U$261, U$274, U$287, U$300, U$313, U$326, U$339, U$352, U$365, U$378, U$391, U$404, U$417, U$430, U$443, U$456, U$469, U$482, U$495, U$508, U$521, U$534, U$547, U$560, U$573, U$586, U$599, U$612, U$625, U$638, U$651, U$664, U$677, U$690, U$703, U$716, U$729, U$742, U$755, U$768, U$781, U$794, U$807, U$820: SFE_LOGO_FLAME_.1

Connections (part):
3.3V: ADDR.1, C1.1, I2C_PU.2, J1.2, R3.2, R4.2, R5.2, TP3.1, U2.P3
3.3V1: ADDR1.1, C2.1, I2C_PU1.2, J2.2, R8.2, R9.2, R10.2, TP7.1, U1.P3
3.3V2: ADDR2.1, C3.1, I2C_PU2.2, J7.2, R13.2, R14.2, R15.2, TP11.1, U3.P3
3.3V3: ADDR3.1, C4.1, I2C_PU3.2, J10.2, R18.2, R19.2, R20.2, TP15.1, U4.P3
3.3V4: ADDR4.1, C5.1, I2C_PU4.2, J13.2, R23.2, R24.2, R25.2, TP19.1, U5.P3
3.3V5: ADDR5.1, C6.1, I2C_PU5.2, J16.2, R28.2, R29.2, R30.2, TP23.1, U6.P3
3.3V6: ADDR6.1, C7.1, I2C_PU6.2, J19.2, R33.2, R34.2, R35.2, TP27.1, U7.P3
3.3V7: ADDR7.1, C8.1, I2C_PU7.2, J22.2, R38.2, R39.2, R40.2, TP31.1, U8.P3
3.3V8: ADDR8.1, C9.1, I2C_PU8.2, J25.2, R43.2, R44.2, R45.2, TP35.1, U9.P3
3.3V9: ADDR9.1, C10.1, I2C_PU9.2, J28.2, R48.2, R49.2, R50.2, TP39.1, U10.P3
3.3V10: ADDR10.1, C11.1, I2C_PU10.2, J31.2, R53.2, R54.2, R55.2, TP43.1, U11.P3
3.3V11: ADDR11.1, C12.1, I2C_PU11.2, J34.2, R58.2, R59.2, R60.2, TP47.1, U12.P3
3.3V12: ADDR12.1, C13.1, I2C_PU12.2, J37.2, R63.2, R64.2, R65.2, TP51.1, U13.P3
3.3V13: ADDR13.1, C14.1, I2C_PU13.2, J40.2, R68.2, R69.2, R70.2, TP55.1, U14.P3
3.3V14: ADDR14.1, C15.1, I2C_PU14.2, J43.2, R73.2, R74.2, R75.2, TP59.1, U15.P3
3.3V15: ADDR15.1, C16.1, I2C_PU15.2, J46.2, R78.2, R79.2, R80.2, TP63.1, U16.P3
3.3V16: ADDR16.1, C17.1, I2C_PU16.2, J49.2, R83.2, R84.2, R85.2, TP67.1, U17.P3
3.3V17: ADDR17.1, C18.1, I2C_PU17.2, J52.2, R88.2, R89.2, R90.2, TP71.1, U18.P3
3.3V18: ADDR18.1, C19.1, I2C_PU18.2, J55.2, R93.2, R94.2, R95.2, TP75.1, U19.P3
3.3V19: ADDR19.1, C20.1, I2C_PU19.2, J58.2, R98.2, R99.2, R100.2, TP79.1, U20.P3
3.3V20: ADDR20.1, C21.1, I2C_PU20.2, J61.2, R103.2, R104.2, R105.2, TP83.1, U21.P3
3.3V21: ADDR21.1, C22.1, I2C_PU21.2, J64.2, R108.2, R109.2, R110.2, TP87.1, U22.P3
3.3V22: ADDR22.1, C23.1, I2C_PU22.2, J67.2, R113.2, R114.2, R115.2, TP91.1, U23.P3
3.3V23: ADDR23.1, C24.1, I2C_PU23.2, J70.2, R118.2, R119.2, R120.2, TP95.1, U24.P3
3.3V24: ADDR24.1, C25.1, I2C_PU24.2, J73.2, R123.2, R124.2, R125.2, TP99.1, U25.P3
3.3V25: ADDR25.1, C26.1, I2C_PU25.2, J76.2, R128.2, R129.2, R130.2, TP103.1, U26.P3
3.3V26: ADDR26.1, C27.1, I2C_PU26.2, J79.2, R133.2, R134.2, R135.2, TP107.1, U27.P3
3.3V27: ADDR27.1, C28.1, I2C_PU27.2, J82.2, R138.2, R139.2, R140.2, TP111.1, U28.P3
3.3V28: ADDR28.1, C29.1, I2C_PU28.2, J85.2, R143.2, R144.2, R145.2, TP115.1, U29.P3
3.3V29: ADDR29.1, C30.1, I2C_PU29.2, J88.2, R148.2, R149.2, R150.2, TP119.1, U30.P3
3.3V30: ADDR30.1, C31.1, I2C_PU30.2, J91.2, R153.2, R154.2, R155.2, TP123.1, U31.P3
3.3V31: ADDR31.1, C32.1, I2C_PU31.2, J94.2, R158.2, R159.2, R160.2, TP127.1, U32.P3
3.3V32: ADDR32.1, C33.1, I2C_PU32.2, J97.2, R163.2, R164.2, R165.2, TP131.1, U33.P3
3.3V33: ADDR33.1, C34.1, I2C_PU33.2, J100.2, R168.2, R169.2, R170.2, TP135.1, U34.P3
3.3V34: ADDR34.1, C35.1, I2C_PU34.2, J103.2, R173.2, R174.2, R175.2, TP139.1, U35.P3
3.3V35: ADDR35.1, C36.1, I2C_PU35.2, J106.2, R178.2, R179.2, R180.2, TP143.1, U36.P3
3.3V36: ADDR36.1, C37.1, I2C_PU36.2, J109.2, R183.2, R184.2, R185.2, TP147.1, U37.P3
3.3V37: ADDR37.1, C38.1, I2C_PU37.2, J112.2, R188.2, R189.2, R190.2, TP151.1, U38.P3
3.3V38: ADDR38.1, C39.1, I2C_PU38.2, J115.2, R193.2, R194.2, R195.2, TP155.1, U39.P3
3.3V39: ADDR39.1, C40.1, I2C_PU39.2, J118.2, R198.2, R199.2, R200.2, TP159.1, U40.P3
3.3V40: ADDR40.1, C41.1, I2C_PU40.2, J121.2, R203.2, R204.2, R205.2, TP163.1, U41.P3
3.3V41: ADDR41.1, C42.1, I2C_PU41.2, J124.2, R208.2, R209.2, R210.2, TP167.1, U42.P3
3.3V42: ADDR42.1, C43.1, I2C_PU42.2, J127.2, R213.2, R214.2, R215.2, TP171.1, U43.P3
3.3V43: ADDR43.1, C44.1, I2C_PU43.2, J130.2, R218.2, R219.2, R220.2, TP175.1, U44.P3
3.3V44: ADDR44.1, C45.1, I2C_PU44.2, J133.2, R223.2, R224.2, R225.2, TP179.1, U45.P3
3.3V45: ADDR45.1, C46.1, I2C_PU45.2, J136.2, R228.2, R229.2, R230.2, TP183.1, U46.P3
3.3V46: ADDR46.1, C47.1, I2C_PU46.2, J139.2, R233.2, R234.2, R235.2, TP187.1, U47.P3
3.3V47: ADDR47.1, C48.1, I2C_PU47.2, J142.2, R238.2, R239.2, R240.2, TP191.1, U48.P3
3.3V48: ADDR48.1, C49.1, I2C_PU48.2, J145.2, R243.2, R244.2, R245.2, TP195.1, U49.P3
3.3V49: ADDR49.1, C50.1, I2C_PU49.2, J148.2, R248.2, R249.2, R250.2, TP199.1, U50.P3
3.3V50: ADDR50.1, C51.1, I2C_PU50.2, J151.2, R253.2, R254.2, R255.2, TP203.1, U51.P3
3.3V51: ADDR51.1, C52.1, I2C_PU51.2, J154.2, R258.2, R259.2, R260.2, TP207.1, U52.P3
3.3V52: ADDR52.1, C53.1, I2C_PU52.2, J157.2, R263.2, R264.2, R265.2, TP211.1, U53.P3
3.3V53: ADDR53.1, C54.1, I2C_PU53.2, J160.2, R268.2, R269.2, R270.2, TP215.1, U54.P3
3.3V54: ADDR54.1, C55.1, I2C_PU54.2, J163.2, R273.2, R274.2, R275.2, TP219.1, U55.P3
3.3V55: ADDR55.1, C56.1, I2C_PU55.2, J166.2, R278.2, R279.2, R280.2, TP223.1, U56.P3
3.3V56: ADDR56.1, C57.1, I2C_PU56.2, J169.2, R283.2, R284.2, R285.2, TP227.1, U57.P3
3.3V57: ADDR57.1, C58.1, I2C_PU57.2, J172.2, R288.2, R289.2, R290.2, TP231.1, U58.P3
3.3V58: ADDR58.1, C59.1, I2C_PU58.2, J175.2, R293.2, R294.2, R295.2, TP235.1, U59.P3
3.3V59: ADDR59.1, C60.1, I2C_PU59.2, J178.2, R298.2, R299.2, R300.2, TP239.1, U60.P3
3.3V60: ADDR60.1, C61.1, I2C_PU60.2, J181.2, R303.2, R304.2, R305.2, TP243.1, U61.P3
3.3V61: ADDR61.1, C62.1, I2C_PU61.2, J184.2, R308.2, R309.2, R310.2, TP247.1, U62.P3
3.3V62: ADDR62.1, C63.1, I2C_PU62.2, J187.2, R313.2, R314.2, R315.2, TP251.1, U63.P3
3.3V63: ADDR63.1, C64.1, I2C_PU63.2, J190.2, R318.2, R319.2, R320.2, TP255.1, U64.P3
!INT!: J3.1, R3.1, U2.P2
!INT!1: J5.1, R9.1, U1.P2
!INT!2: J8.1, R14.1, U3.P2
!INT!3: J11.1, R19.1, U4.P2
!INT!4: J14.1, R24.1, U5.P2
!INT!5: J17.1, R29.1, U6.P2
!INT!6: J20.1, R34.1, U7.P2
!INT!7: J23.1, R39.1, U8.P2
!INT!8: J26.1, R44.1, U9.P2
!INT!9: J29.1, R49.1, U10.P2
!INT!10: J32.1, R54.1, U11.P2
!INT!11: J35.1, R59.1, U12.P2
!INT!12: J38.1, R64.1, U13.P2
!INT!13: J41.1, R69.1, U14.P2
!INT!14: J44.1, R74.1, U15.P2
!INT!15: J47.1, R79.1, U16.P2
!INT!16: J50.1, R84.1, U17.P2
!INT!17: J53.1, R89.1, U18.P2
!INT!18: J56.1, R94.1, U19.P2
!INT!19: J59.1, R99.1, U20.P2
!INT!20: J62.1, R104.1, U21.P2
!INT!21: J65.1, R109.1, U22.P2
!INT!22: J68.1, R114.1, U23.P2
!INT!23: J71.1, R119.1, U24.P2
!INT!24: J74.1, R124.1, U25.P2
!INT!25: J77.1, R129.1, U26.P2
!INT!26: J80.1, R134.1, U27.P2
!INT!27: J83.1, R139.1, U28.P2
!INT!28: J86.1, R144.1, U29.P2
!INT!29: J89.1, R149.1, U30.P2
!INT!30: J92.1, R154.1, U31.P2
!INT!31: J95.1, R159.1, U32.P2
!INT!32: J98.1, R164.1, U33.P2
!INT!33: J101.1, R169.1, U34.P2
!INT!34: J104.1, R174.1, U35.P2
!INT!35: J107.1, R179.1, U36.P2
!INT!36: J110.1, R184.1, U37.P2
!INT!37: J113.1, R189.1, U38.P2
!INT!38: J116.1, R194.1, U39.P2
!INT!39: J119.1, R199.1, U40.P2
!INT!40: J122.1, R204.1, U41.P2
!INT!41: J125.1, R209.1, U42.P2
!INT!42: J128.1, R214.1, U43.P2
!INT!43: J131.1, R219.1, U44.P2
!INT!44: J134.1, R224.1, U45.P2
!INT!45: J137.1, R229.1, U46.P2
!INT!46: J140.1, R234.1, U47.P2
!INT!47: J143.1, R239.1, U48.P2
!INT!48: J146.1, R244.1, U49.P2
!INT!49: J149.1, R249.1, U50.P2
!INT!50: J152.1, R254.1, U51.P2
!INT!51: J155.1, R259.1, U52.P2
!INT!52: J158.1, R264.1, U53.P2
!INT!53: J161.1, R269.1, U54.P2
!INT!54: J164.1, R274.1, U55.P2
!INT!55: J167.1, R279.1, U56.P2
!INT!56: J170.1, R284.1, U57.P2
!INT!57: J173.1, R289.1, U58.P2
!INT!58: J176.1, R294.1, U59.P2
!INT!59: J179.1, R299.1, U60.P2
!INT!60: J182.1, R304.1, U61.P2
!INT!61: J185.1, R309.1, U62.P2
!INT!62: J188.1, R314.1, U63.P2
!INT!63: J191.1, R319.1, U64.P2
ADDR: ADDR.2, U2.P4
ADDR1: ADDR1.2, U1.P4
ADDR2: ADDR2.2, U3.P4
ADDR3: ADDR3.2, U4.P4
ADDR4: ADDR4.2, U5.P4
ADDR5: ADDR5.2, U6.P4
ADDR6: ADDR6.2, U7.P4
ADDR7: ADDR7.2, U8.P4
ADDR8: ADDR8.2, U9.P4
ADDR9: ADDR9.2, U10.P4
ADDR10: ADDR10.2, U11.P4
ADDR11: ADDR11.2, U12.P4
ADDR12: ADDR12.2, U13.P4
ADDR13: ADDR13.2, U14.P4
ADDR14: ADDR14.2, U15.P4
ADDR15: ADDR15.2, U16.P4
ADDR16: ADDR16.2, U17.P4
ADDR17: ADDR17.2, U18.P4
ADDR18: ADDR18.2, U19.P4
ADDR19: ADDR19.2, U20.P4
ADDR20: ADDR20.2, U21.P4
ADDR21: ADDR21.2, U22.P4
ADDR22: ADDR22.2, U23.P4
ADDR23: ADDR23.2, U24.P4
ADDR24: ADDR24.2, U25.P4
ADDR25: ADDR25.2, U26.P4
ADDR26: ADDR26.2, U27.P4
ADDR27: ADDR27.2, U28.P4
ADDR28: ADDR28.2, U29.P4
ADDR29: ADDR29.2, U30.P4
ADDR30: ADDR30.2, U31.P4
ADDR31: ADDR31.2, U32.P4
ADDR32: ADDR32.2, U33.P4
ADDR33: ADDR33.2, U34.P4
ADDR34: ADDR34.2, U35.P4
ADDR35: ADDR35.2, U36.P4
ADDR36: ADDR36.2, U37.P4
ADDR37: ADDR37.2, U38.P4
ADDR38: ADDR38.2, U39.P4
ADDR39: ADDR39.2, U40.P4
ADDR40: ADDR40.2, U41.P4
ADDR41: ADDR41.2, U42.P4
ADDR42: ADDR42.2, U43.P4
ADDR43: ADDR43.2, U44.P4
ADDR44: ADDR44.2, U45.P4
ADDR45: ADDR45.2, U46.P4
ADDR46: ADDR46.2, U47.P4
ADDR47: ADDR47.2, U48.P4
ADDR48: ADDR48.2, U49.P4
ADDR49: ADDR49.2, U50.P4
ADDR50: ADDR50.2, U51.P4
ADDR51: ADDR51.2, U52.P4
ADDR52: ADDR52.2, U53.P4
ADDR53: ADDR53.2, U54.P4
ADDR54: ADDR54.2, U55.P4
ADDR55: ADDR55.2, U56.P4
ADDR56: ADDR56.2, U57.P4
ADDR57: ADDR57.2, U58.P4
ADDR58: ADDR58.2, U59.P4
ADDR59: ADDR59.2, U60.P4
ADDR60: ADDR60.2, U61.P4
ADDR61: ADDR61.2, U62.P4
ADDR62: ADDR62.2, U63.P4
ADDR63: ADDR63.2, U64.P4
GND: C1.2, J1.1, J4.1, LED.1, TP4.1, U2.P5, U2.P7
GND1: C2.2, J2.1, J6.1, LED1.1, TP8.1, U1.P5, U1.P7
GND2: C3.2, J7.1, J9.1, LED2.1, TP12.1, U3.P5, U3.P7
GND3: C4.2, J10.1, J12.1, LED3.1, TP16.1, U4.P5, U4.P7
GND4: C5.2, J13.1, J15.1, LED4.1, TP20.1, U5.P5, U5.P7
GND5: C6.2, J16.1, J18.1, LED5.1, TP24.1, U6.P5, U6.P7
GND6: C7.2, J19.1, J21.1, LED6.1, TP28.1, U7.P5, U7.P7
GND7: C8.2, J22.1, J24.1, LED7.1, TP32.1, U8.P5, U8.P7
GND8: C9.2, J25.1, J27.1, LED8.1, TP36.1, U9.P5, U9.P7
GND9: C10.2, J28.1, J30.1, LED9.1, TP40.1, U10.P5, U10.P7
GND10: C11.2, J31.1, J33.1, LED10.1, TP44.1, U11.P5, U11.P7
GND11: C12.2, J34.1, J36.1, LED11.1, TP48.1, U12.P5, U12.P7
GND12: C13.2, J37.1, J39.1, LED12.1, TP52.1, U13.P5, U13.P7
GND13: C14.2, J40.1, J42.1, LED13.1, TP56.1, U14.P5, U14.P7
GND14: C15.2, J43.1, J45.1, LED14.1, TP60.1, U15.P5, U15.P7
GND15: C16.2, J46.1, J48.1, LED15.1, TP64.1, U16.P5, U16.P7
GND16: C17.2, J49.1, J51.1, LED16.1, TP68.1, U17.P5, U17.P7
GND17: C18.2, J52.1, J54.1, LED17.1, TP72.1, U18.P5, U18.P7
GND18: C19.2, J55.1, J57.1, LED18.1, TP76.1, U19.P5, U19.P7
GND19: C20.2, J58.1, J60.1, LED19.1, TP80.1, U20.P5, U20.P7
GND20: C21.2, J61.1, J63.1, LED20.1, TP84.1, U21.P5, U21.P7
GND21: C22.2, J64.1, J66.1, LED21.1, TP88.1, U22.P5, U22.P7
GND22: C23.2, J67.1, J69.1, LED22.1, TP92.1, U23.P5, U23.P7
GND23: C24.2, J70.1, J72.1, LED23.1, TP96.1, U24.P5, U24.P7
GND24: C25.2, J73.1, J75.1, LED24.1, TP100.1, U25.P5, U25.P7
GND25: C26.2, J76.1, J78.1, LED25.1, TP104.1, U26.P5, U26.P7
GND26: C27.2, J79.1, J81.1, LED26.1, TP108.1, U27.P5, U27.P7
GND27: C28.2, J82.1, J84.1, LED27.1, TP112.1, U28.P5, U28.P7
GND28: C29.2, J85.1, J87.1, LED28.1, TP116.1, U29.P5, U29.P7
GND29: C30.2, J88.1, J90.1, LED29.1, TP120.1, U30.P5, U30.P7
GND30: C31.2, J91.1, J93.1, LED30.1, TP124.1, U31.P5, U31.P7
GND31: C32.2, J94.1, J96.1, LED31.1, TP128.1, U32.P5, U32.P7
GND32: C33.2, J97.1, J99.1, LED32.1, TP132.1, U33.P5, U33.P7
GND33: C34.2, J100.1, J102.1, LED33.1, TP136.1, U34.P5, U34.P7
GND34: C35.2, J103.1, J105.1, LED34.1, TP140.1, U35.P5, U35.P7
GND35: C36.2, J106.1, J108.1, LED35.1, TP144.1, U36.P5, U36.P7
GND36: C37.2, J109.1, J111.1, LED36.1, TP148.1, U37.P5, U37.P7
GND37: C38.2, J112.1, J114.1, LED37.1, TP152.1, U38.P5, U38.P7
GND38: C39.2, J115.1, J117.1, LED38.1, TP156.1, U39.P5, U39.P7
GND39: C40.2, J118.1, J120.1, LED39.1, TP160.1, U40.P5, U40.P7
GND40: C41.2, J121.1, J123.1, LED40.1, TP164.1, U41.P5, U41.P7
GND41: C42.2, J124.1, J126.1, LED41.1, TP168.1, U42.P5, U42.P7
GND42: C43.2, J127.1, J129.1, LED42.1, TP172.1, U43.P5, U43.P7
GND43: C44.2, J130.1, J132.1, LED43.1, TP176.1, U44.P5, U44.P7
GND44: C45.2, J133.1, J135.1, LED44.1, TP180.1, U45.P5, U45.P7
GND45: C46.2, J136.1, J138.1, LED45.1, TP184.1, U46.P5, U46.P7
GND46: C47.2, J139.1, J141.1, LED46.1, TP188.1, U47.P5, U47.P7
GND47: C48.2, J142.1, J144.1, LED47.1, TP192.1, U48.P5, U48.P7
GND48: C49.2, J145.1, J147.1, LED48.1, TP196.1, U49.P5, U49.P7
GND49: C50.2, J148.1, J150.1, LED49.1, TP200.1, U50.P5, U50.P7
GND50: C51.2, J151.1, J153.1, LED50.1, TP204.1, U51.P5, U51.P7
GND51: C52.2, J154.1, J156.1, LED51.1, TP208.1, U52.P5, U52.P7
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

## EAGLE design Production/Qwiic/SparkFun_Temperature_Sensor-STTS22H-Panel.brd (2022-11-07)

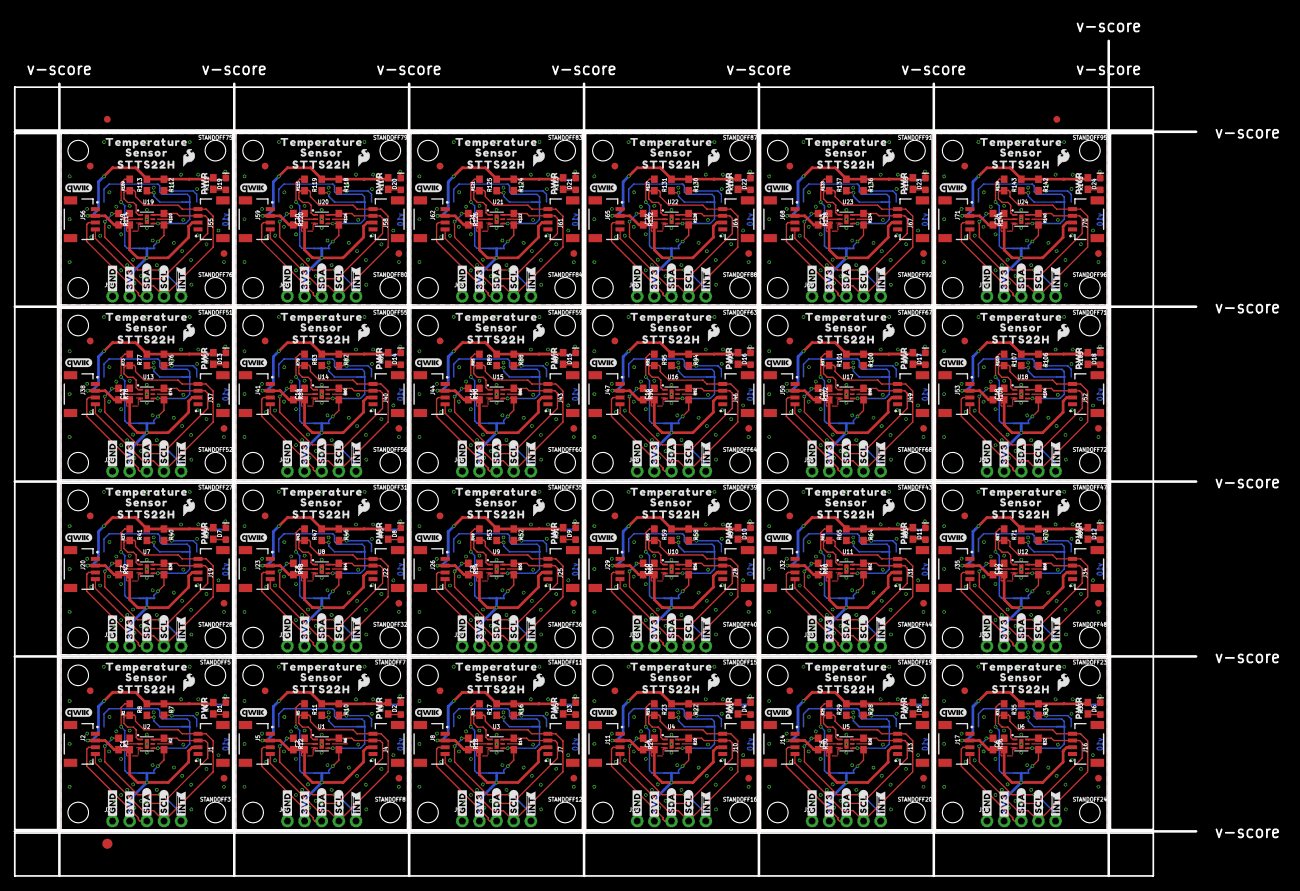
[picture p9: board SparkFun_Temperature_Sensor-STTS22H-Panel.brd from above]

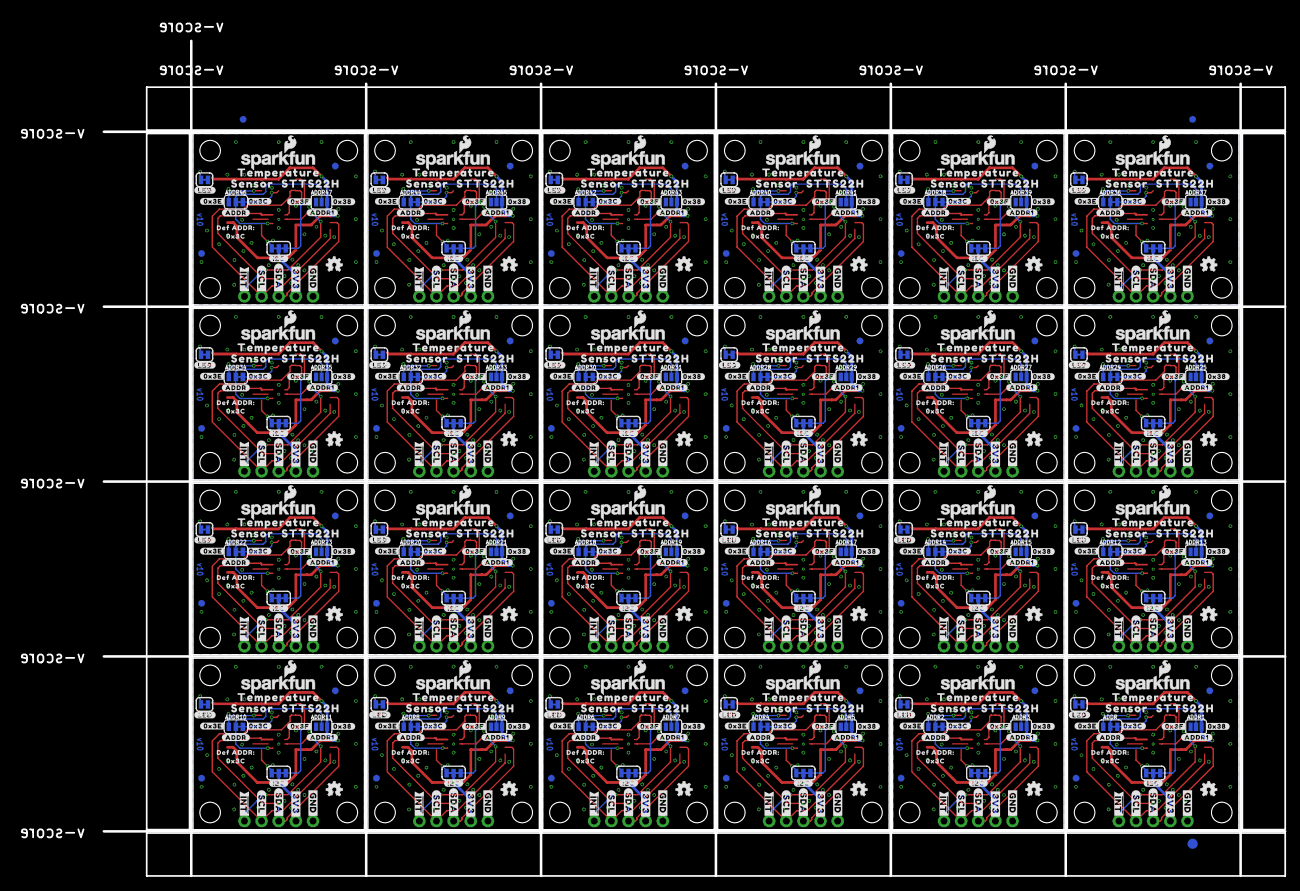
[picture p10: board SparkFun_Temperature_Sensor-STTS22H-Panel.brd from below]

Board: 2 copper layers, 175.0 x 123.7 mm, 1326 parts (627 on the bottom side), 288 nets.

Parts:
ADDR, ADDR2, ADDR4, ADDR6, ADDR8, ADDR10, ADDR12, ADDR14, ADDR16, ADDR18, ADDR20, ADDR22, ADDR24, ADDR26, ADDR28, ADDR30, ADDR32, ADDR34, ADDR36, ADDR38, ADDR40, ADDR42, ADDR44, ADDR46: JUMPER-SMT_3_1-NC_TRACE_SILK; SMT-JUMPER_3_1-NC_TRACE_SILK
ADDR1, ADDR3, ADDR5, ADDR7, ADDR9, ADDR11, ADDR13, ADDR15, ADDR17, ADDR19, ADDR21, ADDR23, ADDR25, ADDR27, ADDR29, ADDR31, ADDR33, ADDR35, ADDR37, ADDR39, ADDR41, ADDR43, ADDR45, ADDR47: JUMPER-SMT_3_NO_SILK; SMT-JUMPER_3_NO_SILK
C1, C2, C3, C4, C5, C6, C7, C8, C9, C10, C11, C12, C13, C14, C15, C16, C17, C18, C19, C20, C21, C22, C23, C24: 0.1uF; 0603
D1, D2, D3, D4, D5, D6, D7, D8, D9, D10, D11, D12, D13, D14, D15, D16, D17, D18, D19, D20, D21, D22, D23, D24: RED; LED-0603
E$1, E$2, E$3, E$4: FIDUCIAL-1X2
E$5, E$6: FIDUCIAL-1.5X3
FD1, FD2, FD3, FD4, FD5, FD6, FD7, FD8, FD9, FD10, FD11, FD12, FD13, FD14, FD15, FD16, FD17, FD18, FD19, FD20, FD21, FD22, FD23, FD24, FD25, FD26, FD27, FD28, FD29, FD30, FD31, FD32, FD33, FD34, FD35, FD36, FD37, FD38, FD39, FD40, FD41, FD42, FD43, FD44, FD45, FD46, FD47, FD48, FD49, FD50, FD51, FD52, FD53, FD54, FD55, FD56, FD57, FD58, FD59, FD60, FD61, FD62, FD63, FD64, FD65, FD66, FD67, FD68, FD69, FD70, FD71, FD72, FD73, FD74, FD75, FD76, FD77, FD78, FD79, FD80, FD81, FD82, FD83, FD84, FD85, FD86, FD87, FD88, FD89, FD90, FD91, FD92, FD93, FD94, FD95, FD96: FIDUCIAL1X2; FIDUCIAL-1X2
I2C_PU, I2C_PU1, I2C_PU2, I2C_PU3, I2C_PU4, I2C_PU5, I2C_PU6, I2C_PU7, I2C_PU8, I2C_PU9, I2C_PU10, I2C_PU11, I2C_PU12, I2C_PU13, I2C_PU14, I2C_PU15, I2C_PU16, I2C_PU17, I2C_PU18, I2C_PU19, I2C_PU20, I2C_PU21, I2C_PU22, I2C_PU23: S_MODE; SMT-JUMPER_3_2-NC_TRACE_SILK
J1, J2, J4, J5, J7, J8, J10, J11, J13, J14, J16, J17, J19, J20, J22, J23, J25, J26, J28, J29, J31, J32, J34, J35, J37, J38, J40, J41, J43, J44, J46, J47, J49, J50, J52, J53, J55, J56, J58, J59, J61, J62, J64, J65, J67, J68, J70, J71: QWIIC_RIGHT_ANGLE; JST04_1MM_RA
J3, J6, J9, J12, J15, J18, J21, J24, J27, J30, J33, J36, J39, J42, J45, J48, J51, J54, J57, J60, J63, J66, J69, J72: 1X05_NO_SILK
LED, LED1, LED2, LED3, LED4, LED5, LED6, LED7, LED8, LED9, LED10, LED11, LED12, LED13, LED14, LED15, LED16, LED17, LED18, LED19, LED20, LED21, LED22, LED23: JUMPER-SMT_2_NC_TRACE_SILK; SMT-JUMPER_2_NC_TRACE_SILK
LOGO1, LOGO2, LOGO7, LOGO10, LOGO13, LOGO16, LOGO19, LOGO22, LOGO25, LOGO28, LOGO31, LOGO34, LOGO37, LOGO40, LOGO43, LOGO46, LOGO49, LOGO52, LOGO55, LOGO58, LOGO61, LOGO64, LOGO67, LOGO70: OSHW-LOGOMINI; OSHW-LOGO-MINI
LOGO3, LOGO5, LOGO8, LOGO11, LOGO14, LOGO17, LOGO20, LOGO23, LOGO26, LOGO29, LOGO32, LOGO35, LOGO38, LOGO41, LOGO44, LOGO47, LOGO50, LOGO53, LOGO56, LOGO59, LOGO62, LOGO65, LOGO68, LOGO71: SFE_LOGO_NAME_FLAME.1_INCH; SFE_LOGO_NAME_FLAME_.1
LOGO4, LOGO6, LOGO9, LOGO12, LOGO15, LOGO18, LOGO21, LOGO24, LOGO27, LOGO30, LOGO33, LOGO36, LOGO39, LOGO42, LOGO45, LOGO48, LOGO51, LOGO54, LOGO57, LOGO60, LOGO63, LOGO66, LOGO69, LOGO72: QWIIC_LOGO_4MM; QWIIC_4MM
R1, R2, R5, R6, R13, R14, R19, R20, R25, R26, R31, R32, R37, R38, R43, R44, R49, R50, R55, R56, R61, R62, R67, R68, R73, R74, R79, R80, R85, R86, R91, R92, R97, R98, R103, R104, R109, R110, R115, R116, R121, R122, R127, R128, R133, R134, R139, R140: 2.2k; 0603
R3, R12, R18, R24, R30, R36, R42, R48, R54, R60, R66, R72, R78, R84, R90, R96, R102, R108, R114, R120, R126, R132, R138, R144: 10k; 0603
R4, R9, R15, R21, R27, R33, R39, R45, R51, R57, R63, R69, R75, R81, R87, R93, R99, R105, R111, R117, R123, R129, R135, R141: 1k; 0603
R7, R10, R16, R22, R28, R34, R40, R46, R52, R58, R64, R70, R76, R82, R88, R94, R100, R106, R112, R118, R124, R130, R136, R142: 56k; 0603
R8, R11, R17, R23, R29, R35, R41, R47, R53, R59, R65, R71, R77, R83, R89, R95, R101, R107, R113, R119, R125, R131, R137, R143: 15k; 0603
STANDOFF1, STANDOFF2, STANDOFF3, STANDOFF4, STANDOFF5, STANDOFF6, STANDOFF7, STANDOFF8, STANDOFF9, STANDOFF10, STANDOFF11, STANDOFF12, STANDOFF13, STANDOFF14, STANDOFF15, STANDOFF16, STANDOFF17, STANDOFF18, STANDOFF19, STANDOFF20, STANDOFF21, STANDOFF22, STANDOFF23, STANDOFF24, STANDOFF25, STANDOFF26, STANDOFF27, STANDOFF28, STANDOFF29, STANDOFF30, STANDOFF31, STANDOFF32, STANDOFF33, STANDOFF34, STANDOFF35, STANDOFF36, STANDOFF37, STANDOFF38, STANDOFF39, STANDOFF40, STANDOFF41, STANDOFF42, STANDOFF43, STANDOFF44, STANDOFF45, STANDOFF46, STANDOFF47, STANDOFF48, STANDOFF49, STANDOFF50, STANDOFF51, STANDOFF52, STANDOFF53, STANDOFF54, STANDOFF55, STANDOFF56, STANDOFF57, STANDOFF58, STANDOFF59, STANDOFF60, STANDOFF61, STANDOFF62, STANDOFF63, STANDOFF64, STANDOFF65, STANDOFF66, STANDOFF67, STANDOFF68, STANDOFF69, STANDOFF70, STANDOFF71, STANDOFF72, STANDOFF73, STANDOFF74, STANDOFF75, STANDOFF76, STANDOFF77, STANDOFF78, STANDOFF79, STANDOFF80, STANDOFF81, STANDOFF82, STANDOFF83, STANDOFF84, STANDOFF85, STANDOFF86, STANDOFF87, STANDOFF88, STANDOFF89, STANDOFF90, STANDOFF91, STANDOFF92, STANDOFF93, STANDOFF94, STANDOFF95, STANDOFF96: STAND-OFFTIGHT; STAND-OFF-TIGHT
U1, U2, U3, U4, U5, U6, U7, U8, U9, U10, U11, U12, U13, U14, U15, U16, U17, U18, U19, U20, U21, U22, U23, U24: STTS22H; UDFN-6L
U$1, U$9, U$31, U$35, U$59, U$63, U$87, U$91, U$115, U$119, U$143, U$147, U$171, U$175, U$199, U$203, U$227, U$231, U$255, U$259, U$283, U$287, U$311, U$315, U$339, U$343, U$367, U$371, U$395, U$399, U$423, U$427, U$451, U$455, U$479, U$483, U$507, U$511, U$535, U$539, U$563, U$567, U$591, U$595, U$619, U$623, U$647, U$651: #GND#3
U$2, U$10, U$32, U$36, U$60, U$64, U$88, U$92, U$116, U$120, U$144, U$148, U$172, U$176, U$200, U$204, U$228, U$232, U$256, U$260, U$284, U$288, U$312, U$316, U$340, U$344, U$368, U$372, U$396, U$400, U$424, U$428, U$452, U$456, U$480, U$484, U$508, U$512, U$536, U$540, U$564, U$568, U$592, U$596, U$620, U$624, U$648, U$652: #3V3#4
U$3, U$33, U$61, U$89, U$117, U$145, U$173, U$201, U$229, U$257, U$285, U$313, U$341, U$369, U$397, U$425, U$453, U$481, U$509, U$537, U$565, U$593, U$621, U$649: #SDA#5
U$4, U$34, U$62, U$90, U$118, U$146, U$174, U$202, U$230, U$258, U$286, U$314, U$342, U$370, U$398, U$426, U$454, U$482, U$510, U$538, U$566, U$594, U$622, U$650: #SCL#4
U$5, U$42, U$70, U$98, U$126, U$154, U$182, U$210, U$238, U$266, U$294, U$322, U$350, U$378, U$406, U$434, U$462, U$490, U$518, U$546, U$574, U$602, U$630, U$658: #SDA#7
U$6, U$41, U$69, U$97, U$125, U$153, U$181, U$209, U$237, U$265, U$293, U$321, U$349, U$377, U$405, U$433, U$461, U$489, U$517, U$545, U$573, U$601, U$629, U$657: #ADDR#6
U$7, U$43, U$71, U$99, U$127, U$155, U$183, U$211, U$239, U$267, U$295, U$323, U$351, U$379, U$407, U$435, U$463, U$491, U$519, U$547, U$575, U$603, U$631, U$659: #SCL#6
U$8, U$44, U$72, U$100, U$128, U$156, U$184, U$212, U$240, U$268, U$296, U$324, U$352, U$380, U$408, U$436, U$464, U$492, U$520, U$548, U$576, U$604, U$632, U$660: #ADDR1#9
U$11, U$38, U$66, U$94, U$122, U$150, U$178, U$206, U$234, U$262, U$290, U$318, U$346, U$374, U$402, U$430, U$458, U$486, U$514, U$542, U$570, U$598, U$626, U$654: ##INT##9
U$12, U$45, U$73, U$101, U$129, U$157, U$185, U$213, U$241, U$269, U$297, U$325, U$353, U$381, U$409, U$437, U$465, U$493, U$521, U$549, U$577, U$605, U$633, U$661: #0X3C#25
U$13, U$46, U$74, U$102, U$130, U$158, U$186, U$214, U$242, U$270, U$298, U$326, U$354, U$382, U$410, U$438, U$466, U$494, U$522, U$550, U$578, U$606, U$634, U$662: #0X3E#25
U$14, U$47, U$75, U$103, U$131, U$159, U$187, U$215, U$243, U$271, U$299, U$327, U$355, U$383, U$411, U$439, U$467, U$495, U$523, U$551, U$579, U$607, U$635, U$663: #0X3F#25
U$15, U$48, U$76, U$104, U$132, U$160, U$188, U$216, U$244, U$272, U$300, U$328, U$356, U$384, U$412, U$440, U$468, U$496, U$524, U$552, U$580, U$608, U$636, U$664: #0X38#25
U$16, U$29, U$57, U$85, U$113, U$141, U$169, U$197, U$225, U$253, U$281, U$309, U$337, U$365, U$393, U$421, U$449, U$477, U$505, U$533, U$561, U$589, U$617, U$645: #LED#11
U$17, U$23, U$49, U$52, U$77, U$80, U$105, U$108, U$133, U$136, U$161, U$164, U$189, U$192, U$217, U$220, U$245, U$248, U$273, U$276, U$301, U$304, U$329, U$332, U$357, U$360, U$385, U$388, U$413, U$416, U$441, U$444, U$469, U$472, U$497, U$500, U$525, U$528, U$553, U$556, U$581, U$584, U$609, U$612, U$637, U$640, U$665, U$668: TEMPERATURE23
U$18, U$37, U$65, U$93, U$121, U$149, U$177, U$205, U$233, U$261, U$289, U$317, U$345, U$373, U$401, U$429, U$457, U$485, U$513, U$541, U$569, U$597, U$625, U$653: ##INT##6
U$19, U$24, U$50, U$53, U$78, U$81, U$106, U$109, U$134, U$137, U$162, U$165, U$190, U$193, U$218, U$221, U$246, U$249, U$274, U$277, U$302, U$305, U$330, U$333, U$358, U$361, U$386, U$389, U$414, U$417, U$442, U$445, U$470, U$473, U$498, U$501, U$526, U$529, U$554, U$557, U$582, U$585, U$610, U$613, U$638, U$641, U$666, U$669: SENSOR24
U$20, U$39, U$67, U$95, U$123, U$151, U$179, U$207, U$235, U$263, U$291, U$319, U$347, U$375, U$403, U$431, U$459, U$487, U$515, U$543, U$571, U$599, U$627, U$655: SFE_LOGO_FLAME_.1
U$21, U$40, U$68, U$96, U$124, U$152, U$180, U$208, U$236, U$264, U$292, U$320, U$348, U$376, U$404, U$432, U$460, U$488, U$516, U$544, U$572, U$600, U$628, U$656: PWR9
U$22, U$26, U$51, U$54, U$79, U$82, U$107, U$110, U$135, U$138, U$163, U$166, U$191, U$194, U$219, U$222, U$247, U$250, U$275, U$278, U$303, U$306, U$331, U$334, U$359, U$362, U$387, U$390, U$415, U$418, U$443, U$446, U$471, U$474, U$499, U$502, U$527, U$530, U$555, U$558, U$583, U$586, U$611, U$614, U$639, U$642, U$667, U$670: STTS22H21
U$25, U$30, U$58, U$86, U$114, U$142, U$170, U$198, U$226, U$254, U$282, U$310, U$338, U$366, U$394, U$422, U$450, U$478, U$506, U$534, U$562, U$590, U$618, U$646: #I2C#11
U$27, U$56, U$84, U$112, U$140, U$168, U$196, U$224, U$252, U$280, U$308, U$336, U$364, U$392, U$420, U$448, U$476, U$504, U$532, U$560, U$588, U$616, U$644, U$672: DEF_ADDR#29
U$28, U$55, U$83, U$111, U$139, U$167, U$195, U$223, U$251, U$279, U$307, U$335, U$363, U$391, U$419, U$447, U$475, U$503, U$531, U$559, U$587, U$615, U$643, U$671: 0X3C30

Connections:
3.3V: ADDR1.3, C1.1, I2C_PU.2, J1.2, J2.2, J3.2, R3.2, R4.2, R7.1, R8.2, U2.P3
3.3V1: ADDR3.3, C2.1, I2C_PU1.2, J4.2, J5.2, J6.2, R9.2, R10.1, R11.2, R12.2, U1.P3
3.3V2: ADDR5.3, C3.1, I2C_PU2.2, J7.2, J8.2, J9.2, R15.2, R16.1, R17.2, R18.2, U3.P3
3.3V3: ADDR7.3, C4.1, I2C_PU3.2, J10.2, J11.2, J12.2, R21.2, R22.1, R23.2, R24.2, U4.P3
3.3V4: ADDR9.3, C5.1, I2C_PU4.2, J13.2, J14.2, J15.2, R27.2, R28.1, R29.2, R30.2, U5.P3
3.3V5: ADDR11.3, C6.1, I2C_PU5.2, J16.2, J17.2, J18.2, R33.2, R34.1, R35.2, R36.2, U6.P3
3.3V6: ADDR13.3, C7.1, I2C_PU6.2, J19.2, J20.2, J21.2, R39.2, R40.1, R41.2, R42.2, U7.P3
3.3V7: ADDR15.3, C8.1, I2C_PU7.2, J22.2, J23.2, J24.2, R45.2, R46.1, R47.2, R48.2, U8.P3
3.3V8: ADDR17.3, C9.1, I2C_PU8.2, J25.2, J26.2, J27.2, R51.2, R52.1, R53.2, R54.2, U9.P3
3.3V9: ADDR19.3, C10.1, I2C_PU9.2, J28.2, J29.2, J30.2, R57.2, R58.1, R59.2, R60.2, U10.P3
3.3V10: ADDR21.3, C11.1, I2C_PU10.2, J31.2, J32.2, J33.2, R63.2, R64.1, R65.2, R66.2, U11.P3
3.3V11: ADDR23.3, C12.1, I2C_PU11.2, J34.2, J35.2, J36.2, R69.2, R70.1, R71.2, R72.2, U12.P3
3.3V12: ADDR25.3, C13.1, I2C_PU12.2, J37.2, J38.2, J39.2, R75.2, R76.1, R77.2, R78.2, U13.P3
3.3V13: ADDR27.3, C14.1, I2C_PU13.2, J40.2, J41.2, J42.2, R81.2, R82.1, R83.2, R84.2, U14.P3
3.3V14: ADDR29.3, C15.1, I2C_PU14.2, J43.2, J44.2, J45.2, R87.2, R88.1, R89.2, R90.2, U15.P3
3.3V15: ADDR31.3, C16.1, I2C_PU15.2, J46.2, J47.2, J48.2, R93.2, R94.1, R95.2, R96.2, U16.P3
3.3V16: ADDR33.3, C17.1, I2C_PU16.2, J49.2, J50.2, J51.2, R99.2, R100.1, R101.2, R102.2, U17.P3
3.3V17: ADDR35.3, C18.1, I2C_PU17.2, J52.2, J53.2, J54.2, R105.2, R106.1, R107.2, R108.2, U18.P3
3.3V18: ADDR37.3, C19.1, I2C_PU18.2, J55.2, J56.2, J57.2, R111.2, R112.1, R113.2, R114.2, U19.P3
3.3V19: ADDR39.3, C20.1, I2C_PU19.2, J58.2, J59.2, J60.2, R117.2, R118.1, R119.2, R120.2, U20.P3
3.3V20: ADDR41.3, C21.1, I2C_PU20.2, J61.2, J62.2, J63.2, R123.2, R124.1, R125.2, R126.2, U21.P3
3.3V21: ADDR43.3, C22.1, I2C_PU21.2, J64.2, J65.2, J66.2, R129.2, R130.1, R131.2, R132.2, U22.P3
3.3V22: ADDR45.3, C23.1, I2C_PU22.2, J67.2, J68.2, J69.2, R135.2, R136.1, R137.2, R138.2, U23.P3
3.3V23: ADDR47.3, C24.1, I2C_PU23.2, J70.2, J71.2, J72.2, R141.2, R142.1, R143.2, R144.2, U24.P3
!INT!: J3.5, R3.1, U2.P2
!INT!1: J6.5, R12.1, U1.P2
!INT!2: J9.5, R18.1, U3.P2
!INT!3: J12.5, R24.1, U4.P2
!INT!4: J15.5, R30.1, U5.P2
!INT!5: J18.5, R36.1, U6.P2
!INT!6: J21.5, R42.1, U7.P2
!INT!7: J24.5, R48.1, U8.P2
!INT!8: J27.5, R54.1, U9.P2
!INT!9: J30.5, R60.1, U10.P2
!INT!10: J33.5, R66.1, U11.P2
!INT!11: J36.5, R72.1, U12.P2
!INT!12: J39.5, R78.1, U13.P2
!INT!13: J42.5, R84.1, U14.P2
!INT!14: J45.5, R90.1, U15.P2
!INT!15: J48.5, R96.1, U16.P2
!INT!16: J51.5, R102.1, U17.P2
!INT!17: J54.5, R108.1, U18.P2
!INT!18: J57.5, R114.1, U19.P2
!INT!19: J60.5, R120.1, U20.P2
!INT!20: J63.5, R126.1, U21.P2
!INT!21: J66.5, R132.1, U22.P2
!INT!22: J69.5, R138.1, U23.P2
!INT!23: J72.5, R144.1, U24.P2
ADDR: ADDR.2, ADDR1.2, U2.P4
ADDR1: ADDR2.2, ADDR3.2, U1.P4
ADDR2: ADDR4.2, ADDR5.2, U3.P4
ADDR3: ADDR6.2, ADDR7.2, U4.P4
ADDR4: ADDR8.2, ADDR9.2, U5.P4
ADDR5: ADDR10.2, ADDR11.2, U6.P4
ADDR6: ADDR12.2, ADDR13.2, U7.P4
ADDR7: ADDR14.2, ADDR15.2, U8.P4
ADDR8: ADDR16.2, ADDR17.2, U9.P4
ADDR9: ADDR18.2, ADDR19.2, U10.P4
ADDR10: ADDR20.2, ADDR21.2, U11.P4
ADDR11: ADDR22.2, ADDR23.2, U12.P4
ADDR12: ADDR24.2, ADDR25.2, U13.P4
ADDR13: ADDR26.2, ADDR27.2, U14.P4
ADDR14: ADDR28.2, ADDR29.2, U15.P4
ADDR15: ADDR30.2, ADDR31.2, U16.P4
ADDR16: ADDR32.2, ADDR33.2, U17.P4
ADDR17: ADDR34.2, ADDR35.2, U18.P4
ADDR18: ADDR36.2, ADDR37.2, U19.P4
ADDR19: ADDR38.2, ADDR39.2, U20.P4
ADDR20: ADDR40.2, ADDR41.2, U21.P4
ADDR21: ADDR42.2, ADDR43.2, U22.P4
ADDR22: ADDR44.2, ADDR45.2, U23.P4
ADDR23: ADDR46.2, ADDR47.2, U24.P4
GND: ADDR1.1, C1.2, J1.1, J2.1, J3.1, LED.1, U2.P5, U2.P7
GND1: ADDR3.1, C2.2, J4.1, J5.1, J6.1, LED1.1, U1.P5, U1.P7
GND2: ADDR5.1, C3.2, J7.1, J8.1, J9.1, LED2.1, U3.P5, U3.P7
GND3: ADDR7.1, C4.2, J10.1, J11.1, J12.1, LED3.1, U4.P5, U4.P7
GND4: ADDR9.1, C5.2, J13.1, J14.1, J15.1, LED4.1, U5.P5, U5.P7
GND5: ADDR11.1, C6.2, J16.1, J17.1, J18.1, LED5.1, U6.P5, U6.P7
GND6: ADDR13.1, C7.2, J19.1, J20.1, J21.1, LED6.1, U7.P5, U7.P7
GND7: ADDR15.1, C8.2, J22.1, J23.1, J24.1, LED7.1, U8.P5, U8.P7
GND8: ADDR17.1, C9.2, J25.1, J26.1, J27.1, LED8.1, U9.P5, U9.P7
GND9: ADDR19.1, C10.2, J28.1, J29.1, J30.1, LED9.1, U10.P5, U10.P7
GND10: ADDR21.1, C11.2, J31.1, J32.1, J33.1, LED10.1, U11.P5, U11.P7
GND11: ADDR23.1, C12.2, J34.1, J35.1, J36.1, LED11.1, U12.P5, U12.P7
GND12: ADDR25.1, C13.2, J37.1, J38.1, J39.1, LED12.1, U13.P5, U13.P7
GND13: ADDR27.1, C14.2, J40.1, J41.1, J42.1, LED13.1, U14.P5, U14.P7
GND14: ADDR29.1, C15.2, J43.1, J44.1, J45.1, LED14.1, U15.P5, U15.P7
GND15: ADDR31.1, C16.2, J46.1, J47.1, J48.1, LED15.1, U16.P5, U16.P7
GND16: ADDR33.1, C17.2, J49.1, J50.1, J51.1, LED16.1, U17.P5, U17.P7
GND17: ADDR35.1, C18.2, J52.1, J53.1, J54.1, LED17.1, U18.P5, U18.P7
GND18: ADDR37.1, C19.2, J55.1, J56.1, J57.1, LED18.1, U19.P5, U19.P7
GND19: ADDR39.1, C20.2, J58.1, J59.1, J60.1, LED19.1, U20.P5, U20.P7
GND20: ADDR41.1, C21.2, J61.1, J62.1, J63.1, LED20.1, U21.P5, U21.P7
GND21: ADDR43.1, C22.2, J64.1, J65.1, J66.1, LED21.1, U22.P5, U22.P7
GND22: ADDR45.1, C23.2, J67.1, J68.1, J69.1, LED22.1, U23.P5, U23.P7
GND23: ADDR47.1, C24.2, J70.1, J71.1, J72.1, LED23.1, U24.P5, U24.P7
unnamed: I2C_PU1.1, R5.2
unnamed: D1.A, R4.1
unnamed: D1.C, LED.2
unnamed: ADDR.3, R8.1
unnamed: I2C_PU.1, R1.2
unnamed: I2C_PU.3, R2.2
unnamed: ADDR.1, R7.2
unnamed: I2C_PU1.3, R6.2
unnamed: D2.A, R9.1
unnamed: D2.C, LED1.2
unnamed: ADDR2.3, R11.1
unnamed: ADDR2.1, R10.2
unnamed: I2C_PU2.1, R13.2
unnamed: I2C_PU2.3, R14.2
unnamed: D3.A, R15.1
unnamed: D3.C, LED2.2
unnamed: ADDR4.3, R17.1
unnamed: ADDR4.1, R16.2
unnamed: I2C_PU3.1, R19.2
unnamed: I2C_PU3.3, R20.2
unnamed: D4.A, R21.1
unnamed: D4.C, LED3.2
unnamed: ADDR6.3, R23.1
unnamed: ADDR6.1, R22.2
unnamed: I2C_PU4.1, R25.2
unnamed: I2C_PU4.3, R26.2
unnamed: D5.A, R27.1
unnamed: D5.C, LED4.2
unnamed: ADDR8.3, R29.1
unnamed: ADDR8.1, R28.2
unnamed: I2C_PU5.1, R31.2
unnamed: I2C_PU5.3, R32.2
unnamed: D6.A, R33.1
unnamed: D6.C, LED5.2
unnamed: ADDR10.3, R35.1
unnamed: ADDR10.1, R34.2
unnamed: I2C_PU6.1, R37.2
unnamed: I2C_PU6.3, R38.2
unnamed: D7.A, R39.1
unnamed: D7.C, LED6.2
unnamed: ADDR12.3, R41.1
unnamed: ADDR12.1, R40.2
unnamed: I2C_PU7.1, R43.2
unnamed: I2C_PU7.3, R44.2
unnamed: D8.A, R45.1
unnamed: D8.C, LED7.2
unnamed: ADDR14.3, R47.1
unnamed: ADDR14.1, R46.2
unnamed: I2C_PU8.1, R49.2
unnamed: I2C_PU8.3, R50.2
unnamed: D9.A, R51.1
unnamed: D9.C, LED8.2
unnamed: ADDR16.3, R53.1
unnamed: ADDR16.1, R52.2
unnamed: I2C_PU9.1, R55.2
unnamed: I2C_PU9.3, R56.2
unnamed: D10.A, R57.1
unnamed: D10.C, LED9.2
unnamed: ADDR18.3, R59.1
unnamed: ADDR18.1, R58.2
unnamed: I2C_PU10.1, R61.2
unnamed: I2C_PU10.3, R62.2
unnamed: D11.A, R63.1
unnamed: D11.C, LED10.2
unnamed: ADDR20.3, R65.1
unnamed: ADDR20.1, R64.2
unnamed: I2C_PU11.1, R67.2
unnamed: I2C_PU11.3, R68.2
unnamed: D12.A, R69.1
unnamed: D12.C, LED11.2
unnamed: ADDR22.3, R71.1
unnamed: ADDR22.1, R70.2
unnamed: I2C_PU12.1, R73.2
unnamed: I2C_PU12.3, R74.2
unnamed: D13.A, R75.1
unnamed: D13.C, LED12.2
unnamed: ADDR24.3, R77.1
unnamed: ADDR24.1, R76.2
unnamed: I2C_PU13.1, R79.2
unnamed: I2C_PU13.3, R80.2
unnamed: D14.A, R81.1
unnamed: D14.C, LED13.2
unnamed: ADDR26.3, R83.1
unnamed: ADDR26.1, R82.2
unnamed: I2C_PU14.1, R85.2
unnamed: I2C_PU14.3, R86.2
unnamed: D15.A, R87.1
unnamed: D15.C, LED14.2
unnamed: ADDR28.3, R89.1
unnamed: ADDR28.1, R88.2
unnamed: I2C_PU15.1, R91.2
unnamed: I2C_PU15.3, R92.2
unnamed: D16.A, R93.1
unnamed: D16.C, LED15.2
unnamed: ADDR30.3, R95.1
unnamed: ADDR30.1, R94.2
unnamed: I2C_PU16.1, R97.2
unnamed: I2C_PU16.3, R98.2
unnamed: D17.A, R99.1
unnamed: D17.C, LED16.2
unnamed: ADDR32.3, R101.1
unnamed: ADDR32.1, R100.2
unnamed: I2C_PU17.1, R103.2
unnamed: I2C_PU17.3, R104.2
unnamed: D18.A, R105.1
unnamed: D18.C, LED17.2
unnamed: ADDR34.3, R107.1
unnamed: ADDR34.1, R106.2
unnamed: I2C_PU18.1, R109.2
unnamed: I2C_PU18.3, R110.2
unnamed: D19.A, R111.1
unnamed: D19.C, LED18.2
unnamed: ADDR36.3, R113.1
unnamed: ADDR36.1, R112.2
unnamed: I2C_PU19.1, R115.2
unnamed: I2C_PU19.3, R116.2
unnamed: D20.A, R117.1
unnamed: D20.C, LED19.2
unnamed: ADDR38.3, R119.1
unnamed: ADDR38.1, R118.2
unnamed: I2C_PU20.1, R121.2
unnamed: I2C_PU20.3, R122.2
unnamed: D21.A, R123.1
unnamed: D21.C, LED20.2
unnamed: ADDR40.3, R125.1
unnamed: ADDR40.1, R124.2
unnamed: I2C_PU21.1, R127.2
unnamed: I2C_PU21.3, R128.2
unnamed: D22.A, R129.1
unnamed: D22.C, LED21.2
unnamed: ADDR42.3, R131.1
unnamed: ADDR42.1, R130.2
unnamed: I2C_PU22.1, R133.2
unnamed: I2C_PU22.3, R134.2
unnamed: D23.A, R135.1
unnamed: D23.C, LED22.2
unnamed: ADDR44.3, R137.1
unnamed: ADDR44.1, R136.2
unnamed: I2C_PU23.1, R139.2
unnamed: I2C_PU23.3, R140.2
unnamed: D24.A, R141.1
unnamed: D24.C, LED23.2
unnamed: ADDR46.3, R143.1
unnamed: ADDR46.1, R142.2
SCL: J1.4, J2.4, J3.4, R1.1, U2.P1
SCL1: J4.4, J5.4, J6.4, R5.1, U1.P1
SCL2: J7.4, J8.4, J9.4, R13.1, U3.P1
SCL3: J10.4, J11.4, J12.4, R19.1, U4.P1
SCL4: J13.4, J14.4, J15.4, R25.1, U5.P1
SCL5: J16.4, J17.4, J18.4, R31.1, U6.P1
SCL6: J19.4, J20.4, J21.4, R37.1, U7.P1
SCL7: J22.4, J23.4, J24.4, R43.1, U8.P1
SCL8: J25.4, J26.4, J27.4, R49.1, U9.P1
SCL9: J28.4, J29.4, J30.4, R55.1, U10.P1
SCL10: J31.4, J32.4, J33.4, R61.1, U11.P1
SCL11: J34.4, J35.4, J36.4, R67.1, U12.P1
SCL12: J37.4, J38.4, J39.4, R73.1, U13.P1
SCL13: J40.4, J41.4, J42.4, R79.1, U14.P1
SCL14: J43.4, J44.4, J45.4, R85.1, U15.P1
SCL15: J46.4, J47.4, J48.4, R91.1, U16.P1
SCL16: J49.4, J50.4, J51.4, R97.1, U17.P1
SCL17: J52.4, J53.4, J54.4, R103.1, U18.P1
SCL18: J55.4, J56.4, J57.4, R109.1, U19.P1
SCL19: J58.4, J59.4, J60.4, R115.1, U20.P1
SCL20: J61.4, J62.4, J63.4, R121.1, U21.P1
SCL21: J64.4, J65.4, J66.4, R127.1, U22.P1
SCL22: J67.4, J68.4, J69.4, R133.1, U23.P1
SCL23: J70.4, J71.4, J72.4, R139.1, U24.P1
SDA: J1.3, J2.3, J3.3, R2.1, U2.P6
SDA1: J4.3, J5.3, J6.3, R6.1, U1.P6
SDA2: J7.3, J8.3, J9.3, R14.1, U3.P6
SDA3: J10.3, J11.3, J12.3, R20.1, U4.P6
SDA4: J13.3, J14.3, J15.3, R26.1, U5.P6
SDA5: J16.3, J17.3, J18.3, R32.1, U6.P6
SDA6: J19.3, J20.3, J21.3, R38.1, U7.P6
SDA7: J22.3, J23.3, J24.3, R44.1, U8.P6
SDA8: J25.3, J26.3, J27.3, R50.1, U9.P6
SDA9: J28.3, J29.3, J30.3, R56.1, U10.P6
SDA10: J31.3, J32.3, J33.3, R62.1, U11.P6
SDA11: J34.3, J35.3, J36.3, R68.1, U12.P6
SDA12: J37.3, J38.3, J39.3, R74.1, U13.P6
SDA13: J40.3, J41.3, J42.3, R80.1, U14.P6
SDA14: J43.3, J44.3, J45.3, R86.1, U15.P6
SDA15: J46.3, J47.3, J48.3, R92.1, U16.P6
SDA16: J49.3, J50.3, J51.3, R98.1, U17.P6
SDA17: J52.3, J53.3, J54.3, R104.1, U18.P6
SDA18: J55.3, J56.3, J57.3, R110.1, U19.P6
SDA19: J58.3, J59.3, J60.3, R116.1, U20.P6
SDA20: J61.3, J62.3, J63.3, R122.1, U21.P6
SDA21: J64.3, J65.3, J66.3, R128.1, U22.P6
SDA22: J67.3, J68.3, J69.3, R134.1, U23.P6
SDA23: J70.3, J71.3, J72.3, R140.1, U24.P6

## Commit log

2022-11-02 Removes ADDR pin from header
    * Routes board
    [SparkFun_Temperatre_Sensor-STTS22H.brd, SparkFun_Temperatre_Sensor-STTS22H.sch]
2022-11-02 Adds tkeepout to temperature sensor
2022-11-02 Adds silk
    [SparkFun_Temperatre_Sensor-STTS22H.brd, SparkFun_Temperatre_Sensor-STTS22H.sch]
2022-11-02 Adds decoupling cap which resulted in additional routing
    [SparkFun_Temperatre_Sensor-STTS22H.brd, SparkFun_Temperatre_Sensor-STTS22H.sch]
2022-11-02 Adds Qwiic Micro shell of a design
    * Adds folders for hardware files
    [SparkFun_Micro_Temperature_Sensor-STTS22H.brd, SparkFun_Micro_Temperature_Sensor-STTS22H.sch, SparkFun_Temperatre_Sensor-STTS22H.brd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]
2022-11-03 Routes Micro, adds silk
    [SparkFun_Micro_Temperature_Sensor-STTS22H.brd, SparkFun_Micro_Temperature_Sensor-STTS22H.sch]
2022-11-03 Adds note for default addresses
    [SparkFun_Micro_Temperature_Sensor-STTS22H.brd, SparkFun_Micro_Temperature_Sensor-STTS22H.sch, SparkFun_Temperatre_Sensor-STTS22H.brd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]
2022-11-04 Fixes off center footprint, adds center pad on temp sensor to ground
    *
    [SparkFun_Micro_Temperature_Sensor-STTS22H.brd, SparkFun_Micro_Temperature_Sensor-STTS22H.sch, SparkFun_Temperatre_Sensor-STTS22H.brd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]
2022-11-04 Adds alternative board with exposed copper on the underside
    [SparkFun_Temperatre_Sensor-STTS22H_ALT.brd, SparkFun_Temperatre_Sensor-STTS22H_ALT.sch]
2022-11-04 Removes alternate version
    [SparkFun_Temperatre_Sensor-STTS22H_ALT.brd, SparkFun_Temperatre_Sensor-STTS22H_ALT.sch]
2022-11-04 Moves OSHW logo, approves various DRC errors, moves silk
    [SparkFun_Temperatre_Sensor-STTS22H.brd]
2022-11-04 Moves address jumper for better symmetry
    [SparkFun_Temperatre_Sensor-STTS22H.brd]
2022-11-04 Adds a single, incredibly important via
    [SparkFun_Temperatre_Sensor-STTS22H.brd]
2022-11-04 re-adds the missing tstop to the temperature sensor
    [SparkFun_Micro_Temperature_Sensor-STTS22H.brd, SparkFun_Micro_Temperature_Sensor-STTS22H.sch, SparkFun_Temperatre_Sensor-STTS22H.brd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]
2022-11-04 Updates temp sensor footprint, Adds bstop underneath IC
    * Adds via directly underneath sensor for better temperature sensing
    * Fixes various routing inconsistencies
    [SparkFun_Micro_Temperature_Sensor-STTS22H.brd, SparkFun_Micro_Temperature_Sensor-STTS22H.sch, SparkFun_Temperatre_Sensor-STTS22H.brd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]
2022-11-04 Fixes units overlap text with design by text
    [SparkFun_Micro_Temperature_Sensor-STTS22H.brd]
2022-11-04 Moves address selection around to be more clear in the schematic
    * Changes second address option on micro to 3v3 instead of GND
    [SparkFun_Micro_Temperature_Sensor-STTS22H.brd, SparkFun_Micro_Temperature_Sensor-STTS22H.sch, SparkFun_Temperatre_Sensor-STTS22H.sch]
2022-11-04 Updates address selection text in schematic to be more clear
    [SparkFun_Micro_Temperature_Sensor-STTS22H.sch]
2022-11-04 Adds the "u" in temperature
    [SparkFun_Temperature_Sensor-STTS22H.brd, SparkFun_Temperature_Sensor-STTS22H.sch]
2022-11-04 Updates temp sensor footprint to have reduced pasted on center pad
    [SparkFun_Micro_Temperature_Sensor-STTS22H.brd, SparkFun_Micro_Temperature_Sensor-STTS22H.sch, SparkFun_Temperature_Sensor-STTS22H.brd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]
2022-11-07 Adds default address text
    [SparkFun_Temperature_Sensor-STTS22H.brd]
2022-11-07 Adds production files for Qwiic version
    [SparkFun_Temperature_Sensor-STTS22H-Panel.GBL, SparkFun_Temperature_Sensor-STTS22H-Panel.GBP, SparkFun_Temperature_Sensor-STTS22H-Panel.GBS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]
2022-11-07 Adds Production files for Qwiic Micro
    [SparkFun_Micro_Temperature_Sensor-STTS22H-Panel.GBL, SparkFun_Micro_Temperature_Sensor-STTS22H-Panel.GBP, SparkFun_Micro_Temperature_Sensor-STTS22H-Panel.GBS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]
2022-11-07 Re-panelizes Qwiic Micro
    [SparkFun_Micro_Temperature_Sensor-STTS22H-Panel.brd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]
2022-11-09 Adds new Qwiic Micro panel
    [SparkFun_Micro_Temperature_Sensor-STTS22H-Panel.GBL, SparkFun_Micro_Temperature_Sensor-STTS22H-Panel.GBP, SparkFun_Micro_Temperature_Sensor-STTS22H-Panel.GBS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]
2022-11-09 Moves qwiic micro panel to production folder
    [SparkFun_Micro_Temperature_Sensor-STTS22H-Panel.GBL, SparkFun_Micro_Temperature_Sensor-STTS22H-Panel.GBP, SparkFun_Micro_Temperature_Sensor-STTS22H-Panel.GBS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]
2022-11-29 Replaces r7 with a 57.6k resistor
    [SparkFun_Temperature_Sensor-STTS22H.brd, SparkFun_Temperature_Sensor-STTS22H.sch]
2022-11-29 Adds 56k to R7
    [SparkFun_Temperature_Sensor-STTS22H.brd, SparkFun_Temperature_Sensor-STTS22H.sch]

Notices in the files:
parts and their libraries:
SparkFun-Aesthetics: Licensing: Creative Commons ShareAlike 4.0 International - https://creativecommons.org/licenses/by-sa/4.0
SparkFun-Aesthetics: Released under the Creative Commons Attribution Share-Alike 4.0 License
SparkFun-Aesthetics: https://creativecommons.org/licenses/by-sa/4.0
